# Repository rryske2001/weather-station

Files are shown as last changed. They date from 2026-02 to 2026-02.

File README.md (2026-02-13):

# 🌦️ Stacja Pogodowa ESP32 (Weather Station)








Projekt zaawansowanej, bezprzewodowej stacji pogodowej podzielonej na moduł bazowy (wyświetlacz) oraz zdalny węzeł czujnikowy. System monitoruje parametry środowiskowe w czasie rzeczywistym, prezentując dane na kolorowym wyświetlaczu TFT oraz rysując wykresy historyczne.

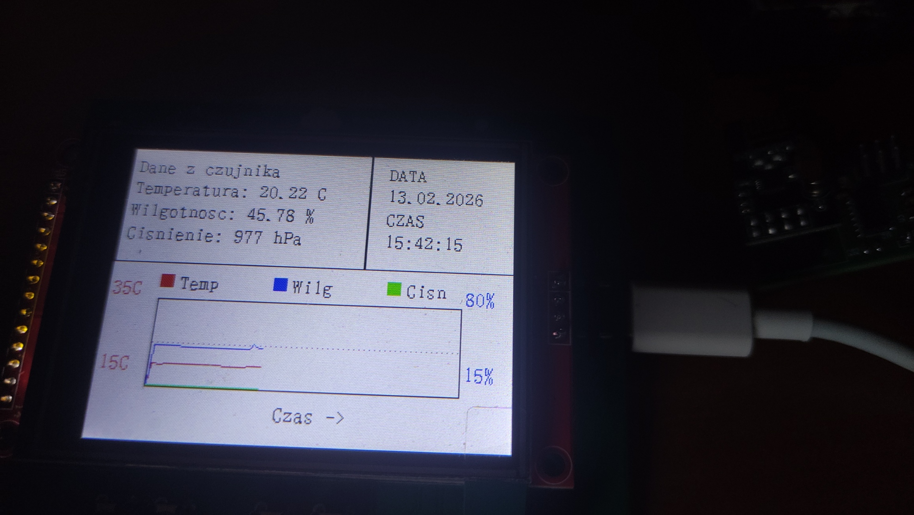
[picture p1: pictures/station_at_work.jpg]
Main Station

*Stacja w trakcie pracy - prezentacja aktualnych danych pomiarowych.*

## 🚀 Główne Funkcjonalności

* **Architektura Rozproszona:** Komunikacja bezprzewodowa między czujnikiem zewnętrznym a bazą przy użyciu modułów radiowych **NRF24L01** (2.4 GHz).
* **Interfejs Graficzny:** Wyświetlacz TFT LCD prezentujący:
    * Aktualną temperaturę, wilgotność i ciśnienie.
    * Wykresy historyczne (rysowanie linii w czasie rzeczywistym).
    * Aktualną datę i godzinę.
* **Synchronizacja Czasu:** Obsługa WiFi i protokołu NTP do automatycznego ustawiania zegara.
* **Sterowanie:** Fizyczne przyciski (SW1, SW2) do nawigacji między ekranami (dane liczbowe / wykresy).
* **Własne PCB:** Zaprojektowane od podstaw płytki drukowane dla obu modułów.

## 🛠️ Specyfikacja Sprzętowa (Hardware)

Projekt sprzętowy został wykonany w środowisku **KiCad**. Pliki produkcyjne znajdują się w katalogu `hardware`.

### 1. Moduł Wewnętrzny (Base Unit)
Centralna jednostka odbierająca dane i wyświetlająca wyniki.
* **MCU:** ESP32-WROOM-32E.
* **Komunikacja:** NRF24L01+ (Odbiornik) + WiFi.
* **Wyświetlacz:** TFT LCD (SPI).
* **Interfejs:** USB-C (zasilanie i programowanie przez układ CH340C).
* **PCB:** Dwuwarstwowa, elementy SMD i THT.

### 2. Moduł Zewnętrzny (Sensor Node)
Energooszczędny moduł pomiarowy.
* **MCU:** ATMEL AVR ATtiny 414.
* **Komunikacja:** NRF24L01+ (Nadajnik).
* **Czujniki:** Zintegrowany sensor środowiskowy (BME280).
* **PCB:** Kompaktowa płytka zoptymalizowana pod zasilanie bateryjne.

## 💻 Struktura Projektu (Software)

Kod źródłowy podzielony jest na dwa niezależne projekty w katalogu `software`:

```text
software/
├── external_module/        # Firmware nadajnika (zewnętrznego)
│   ├── src/                # Kod źródłowy C++
│   ├── platformio.ini      # Konfiguracja środowiska PlatformIO
│   └── ...
└── internal-module-podw/   # Firmware stacji bazowej (ESP32)
    ├── main/               # Główna logika aplikacji (ESP-IDF)
    ├── components/         # Sterowniki (LCD, NRF24, WiFi)
    ├── CMakeLists.txt      # Konfiguracja budowania ESP-IDF
    └── ...

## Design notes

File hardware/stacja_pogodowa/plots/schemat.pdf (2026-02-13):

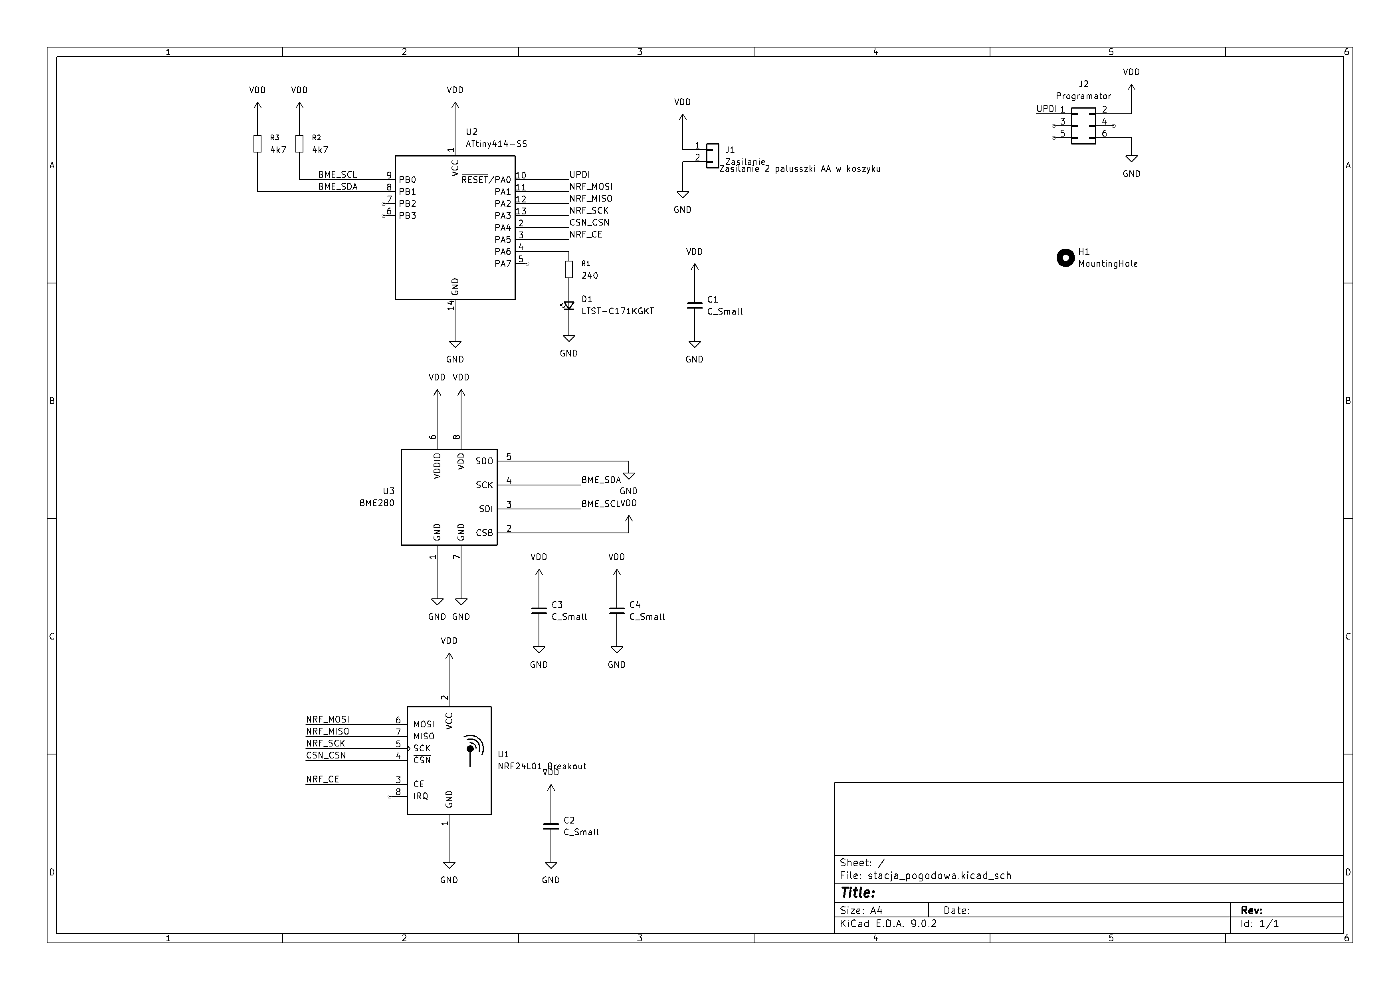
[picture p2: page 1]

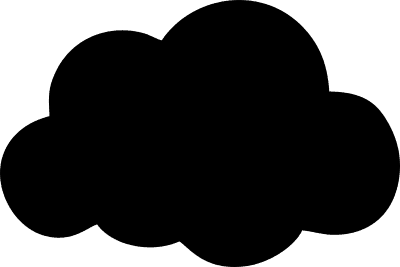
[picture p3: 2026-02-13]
hardware/stacja_pogody_moduł_wew/chmurka.png

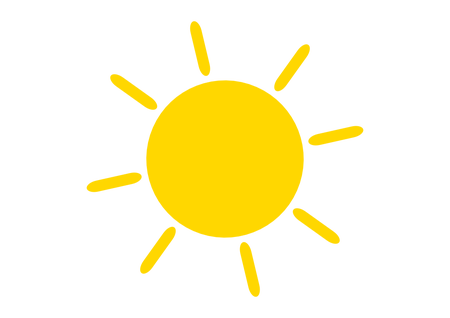
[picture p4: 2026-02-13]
hardware/stacja_pogody_moduł_wew/sloneczko.png

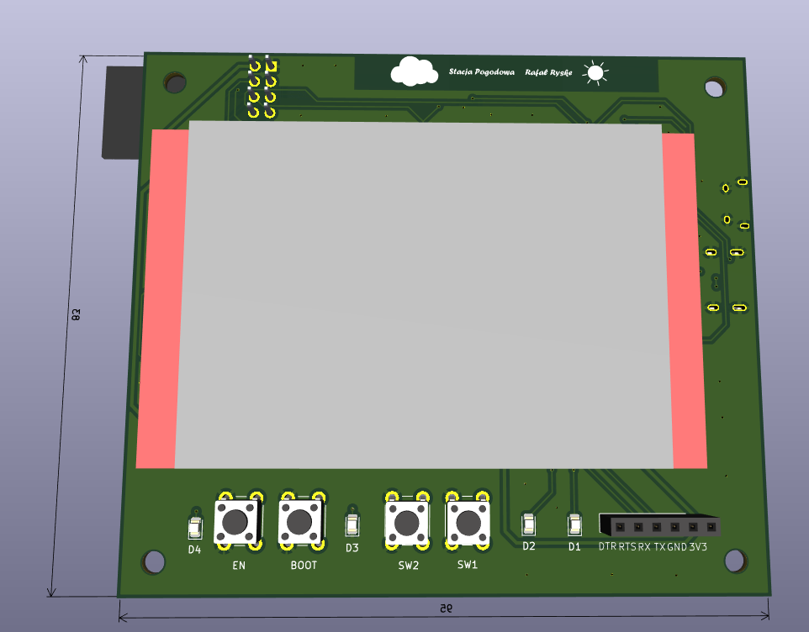
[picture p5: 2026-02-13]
pictures/top_pcb.png

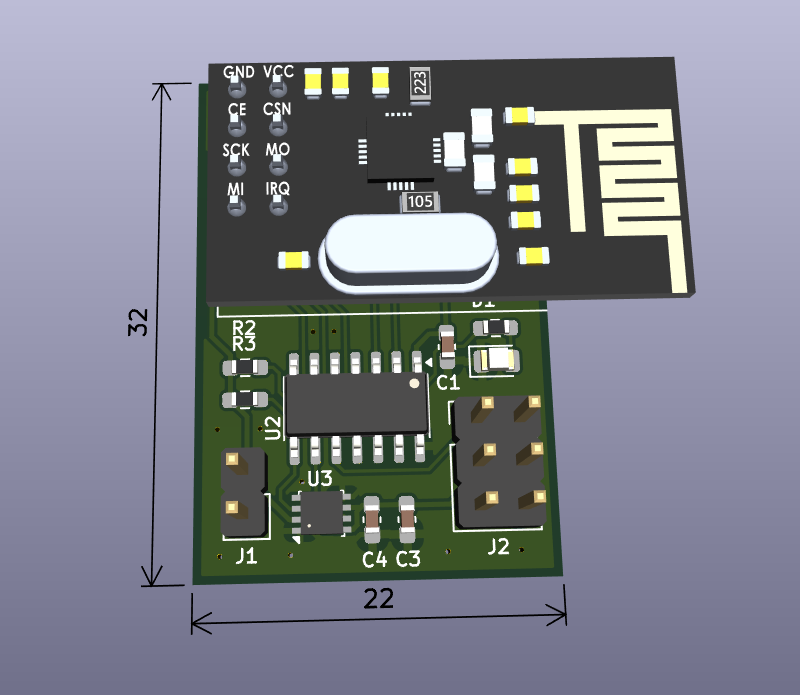
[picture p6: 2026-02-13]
pictures/top_pcb_external.png

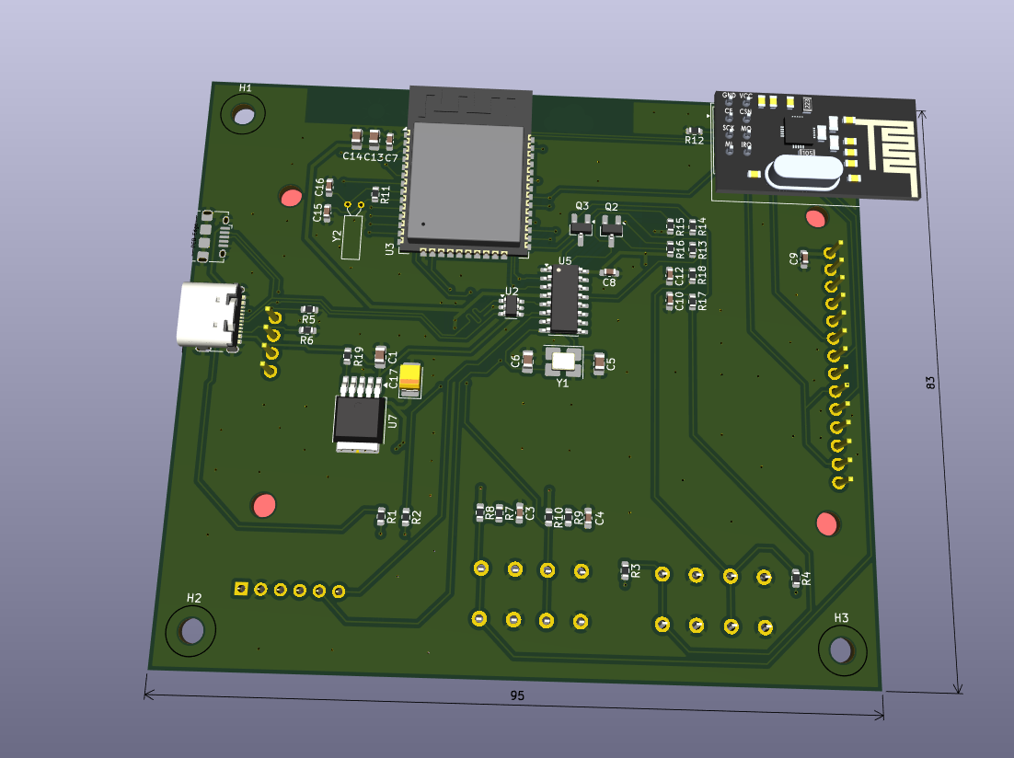
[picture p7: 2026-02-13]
pictures/bottom_pcb.png

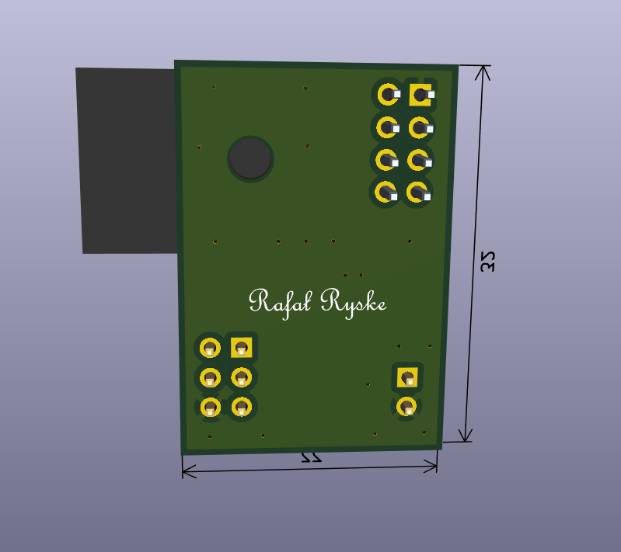
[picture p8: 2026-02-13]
pictures/bottom_pcb_external.png

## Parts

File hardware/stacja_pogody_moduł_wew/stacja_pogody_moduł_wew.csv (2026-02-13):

Reference | Qty | Value | DNP | Exclude from BOM | Exclude from Board | Footprint | Datasheet
C1,C4,C5,C6,C7,C9,C12,C13 | 8 | 100n |  |  |  | Capacitor_SMD:C_0603_1608Metric_Pad1.08x0.95mm_HandSolder | ~
C2,C3 | 2 | 10u |  |  |  | Capacitor_SMD:C_0805_2012Metric_Pad1.18x1.45mm_HandSolder | CS2012X5R106K160NRE
C10,C11 | 2 | 22p |  |  |  | Capacitor_SMD:C_0805_2012Metric_Pad1.18x1.45mm_HandSolder | ~
D1,D2,D3,D4 | 4 | LTST-C171KGKT |  |  |  | LED_SMD:LED_0805_2012Metric | ~
J1 | 1 | 10118194-0001LF |  |  |  | Connector_USB:USB_Micro-B_Amphenol_10118194-0001LF_Horizontal | ~
J2 | 1 | Conn_01x06 |  |  |  | Connector_PinSocket_2.54mm:PinSocket_1x06_P2.54mm_Vertical | ~
J3 | 1 | USB_C_Receptacle_USB2.0_16P |  |  |  |  | https://www.usb.org/sites/default/files/documents/usb_type-c.zip
Q1,Q2 | 2 | NPN |  |  |  | Package_TO_SOT_SMD:SOT-23_Handsoldering | https://ngspice.sourceforge.io/docs/ngspice-html-manual/manual.xhtml#cha_BJTs
R1,R2,R13,R14 | 4 | 240 |  |  |  | Resistor_SMD:R_0603_1608Metric | ~
R3,R4,R5,R6,R10,R12 | 6 | 1k |  |  |  | Resistor_SMD:R_0603_1608Metric | ~
R7,R8,R9,R11 | 4 | 10k |  |  |  | Resistor_SMD:R_0603_1608Metric | ~
SW1,SW2,SW3,SW5 | 4 | SW_MEC_5G |  |  |  | Button_Switch_THT:SW_PUSH_6mm_H4.3mm | http://www.apem.com/int/index.php?controller=attachment&id_attachment=488
U1 | 1 | NRF24L01_Breakout |  |  |  | RF_Module:nRF24L01_Breakout | http://www.nordicsemi.com/eng/content/download/2730/34105/file/nRF24L01_Product_Specification_v2_0.pdf
U2 | 1 | LCD |  |  |  | Wyswietlacz_LCD:LCD_2_8
U3 | 1 | LM1117RS-3.3V |  |  |  | Package_TO_SOT_SMD:TO-252-2 | http://www.ti.com/lit/ds/symlink/lm1117.pdf
U4 | 1 | ESP32-WROOM-32E-N4 |  |  |  | RF_Module:ESP32-WROOM-32E | https://www.espressif.com/sites/default/files/documentation/esp32-wroom-32e_esp32-wroom-32ue_datasheet_en.pdf
U5 | 1 | CH340G |  |  |  | Package_SO:SOIC-16_3.9x9.9mm_P1.27mm | http://www.datasheet5.com/pdf-local-2195953
Y2 | 1 | 3225-12M-SR |  |  |  | Crystal:Crystal_SMD_3225-4Pin_3.2x2.5mm_HandSoldering | ~

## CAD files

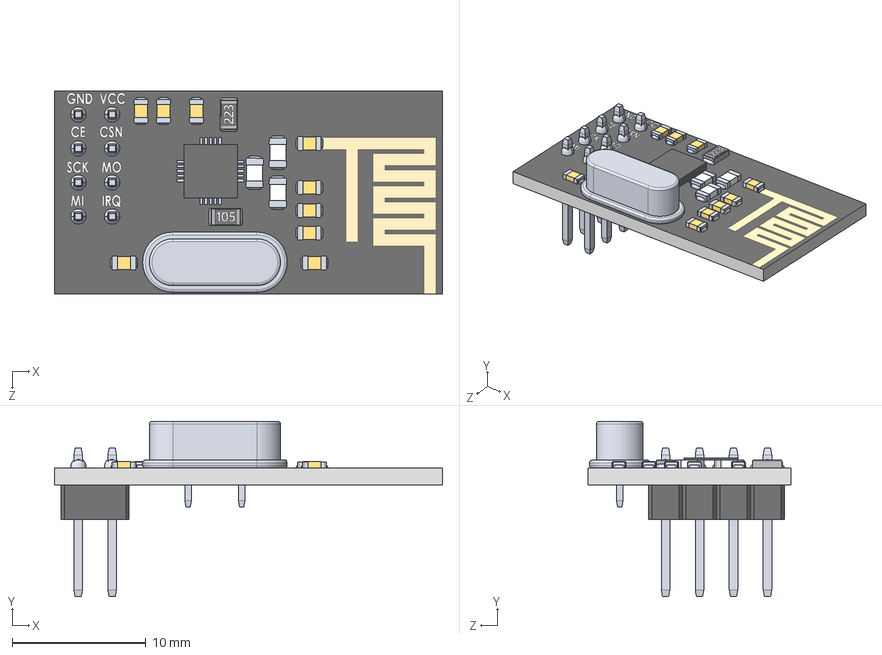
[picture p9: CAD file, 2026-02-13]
hardware/stacja_pogodowa/Wireless Radio Transmitter and Receiver nRF24L01.STEP
29.0 x 13.1 x 15.2 mm
nrfboard
CrystalOscillator
doubleMaleHeader x 4
solder x 8
1.7mmSmdCeramicCapacitor x 9
smdResistor223
smdResistor105
smdceramiccapacitorwhite x 3
4x4SMDchip

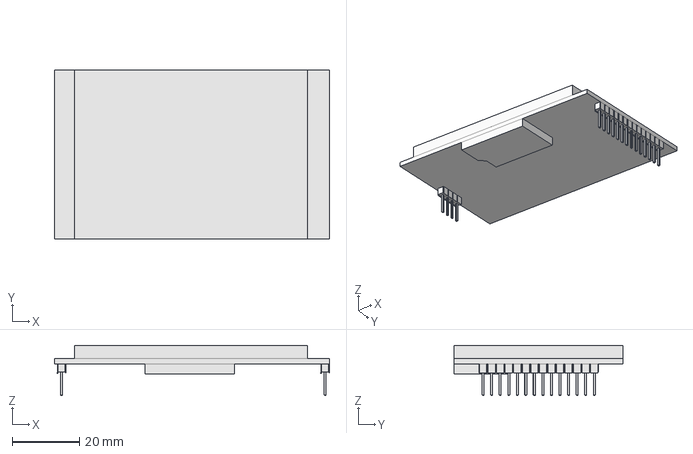
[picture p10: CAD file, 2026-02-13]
hardware/stacja_pogody_moduł_wew/lcd_fusion.FCStd
81.7 x 50.2 x 15.0 mm

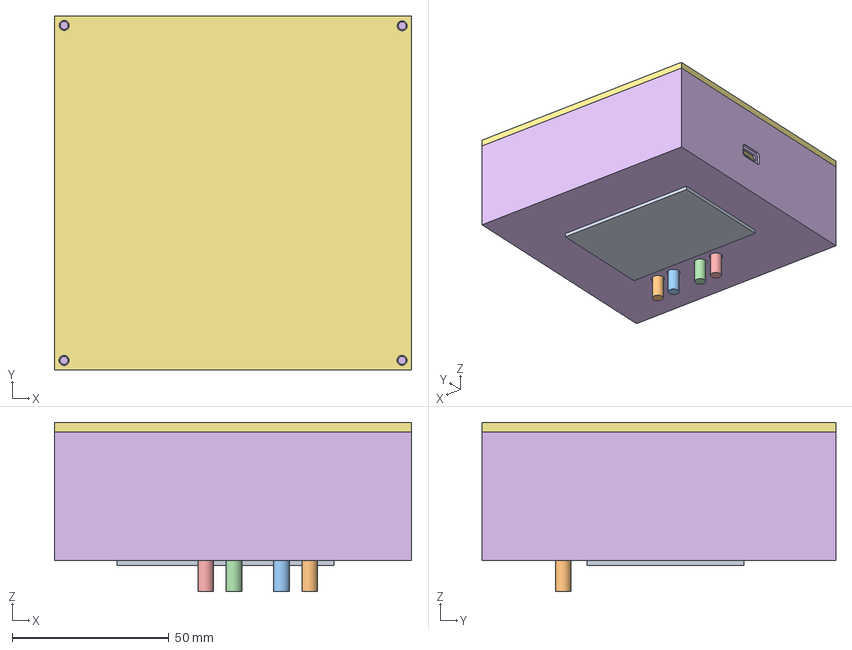
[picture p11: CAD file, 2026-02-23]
obudowa_modul_wew/zlozenie.FCStd
114.0 x 113.0 x 54.0 mm
stacja_pogody_moduł_wew1_001
nakladka_przycisk-nakladka1_001
nakladka_przycisk-nakladka1_002
nakladka_przycisk-nakladka1_003
nakladka_przycisk-nakladka1_004
obudowa_zewn-Zawartość1_001
obudowa_zewn-wieczko1_001

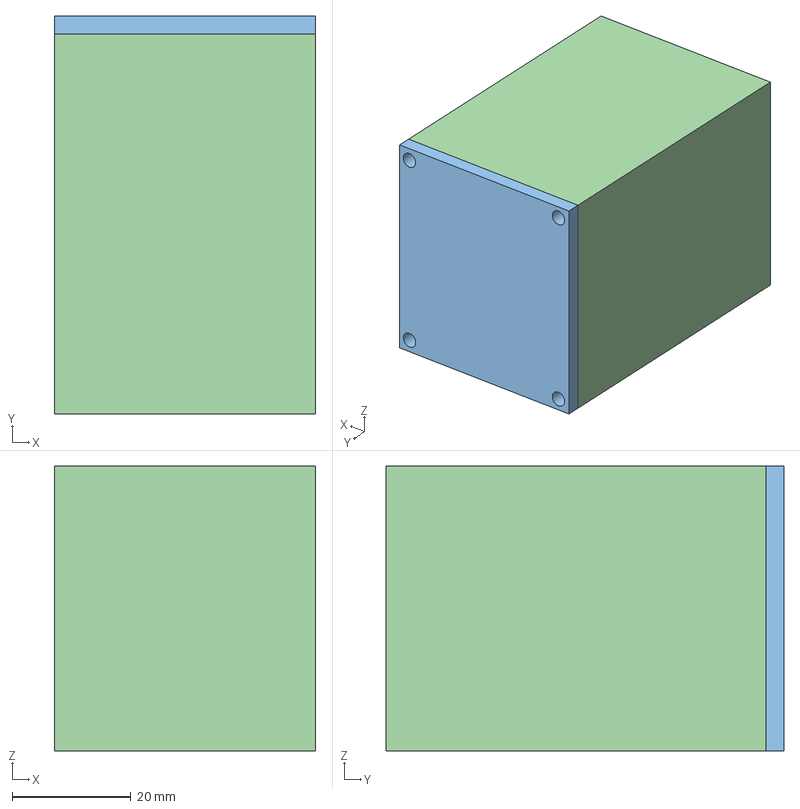
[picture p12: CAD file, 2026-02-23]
obudowa_modul_zewn_v2/obudowa_zewn.FCStd
44.0 x 67.0 x 48.0 mm
stacja_pogodowa
Zawartość
obudowa

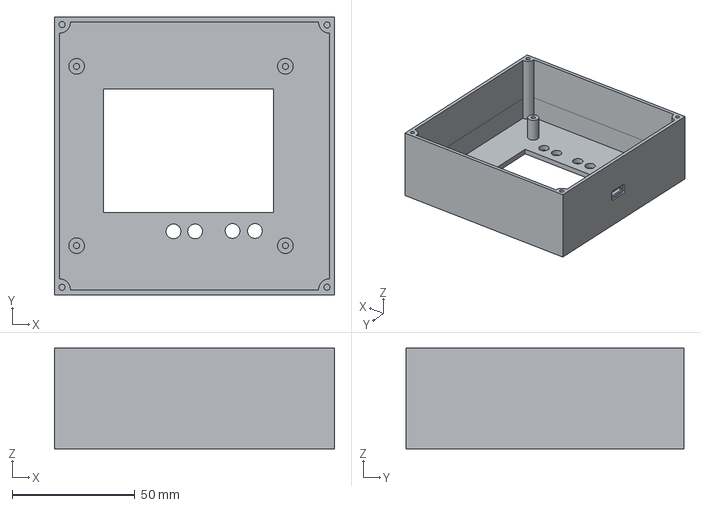
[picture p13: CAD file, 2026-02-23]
obudowa_modul_wew/obudowa_zewn-Zawartość.step
114.0 x 113.0 x 41.0 mm

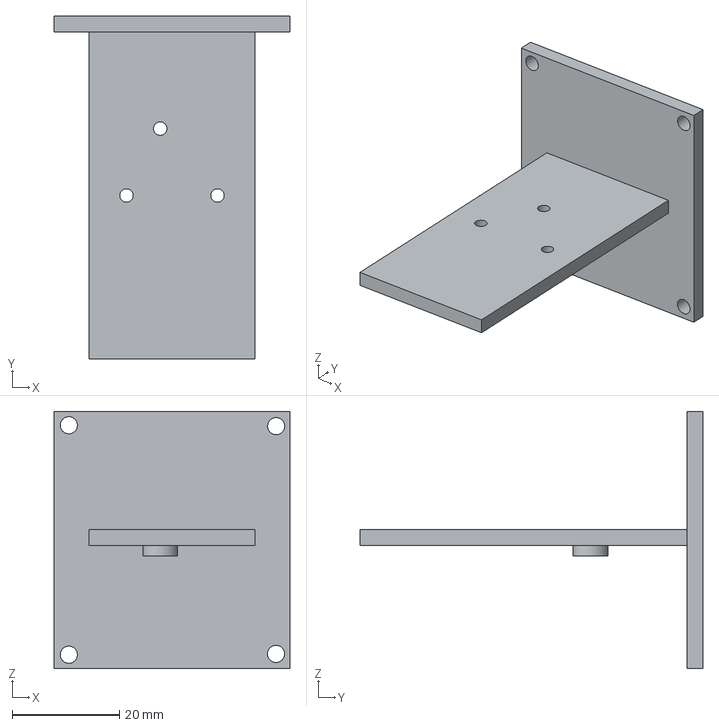
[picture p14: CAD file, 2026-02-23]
obudowa_modul_zewn_v2/obudowa_zewn-Zawartość.step
44.0 x 64.0 x 48.0 mm

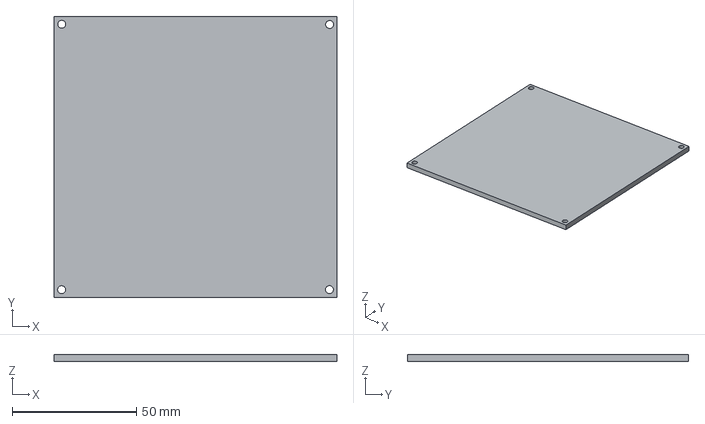
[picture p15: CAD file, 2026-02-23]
obudowa_modul_wew/obudowa_zewn-wieczko.step
114.0 x 113.0 x 3.00 mm

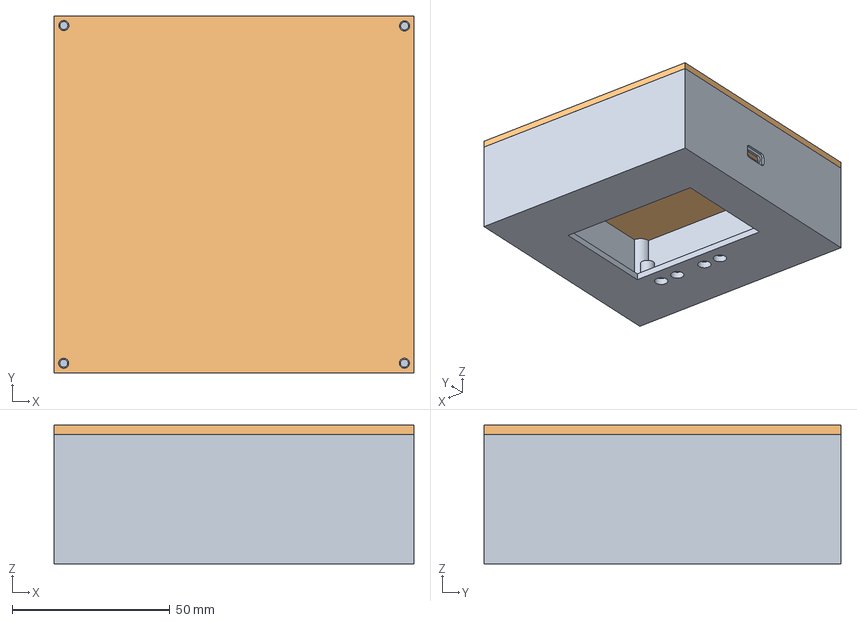
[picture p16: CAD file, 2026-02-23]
obudowa_modul_wew/obudowa_zewn.FCStd
114.0 x 113.0 x 44.0 mm
Zawartość
wieczko

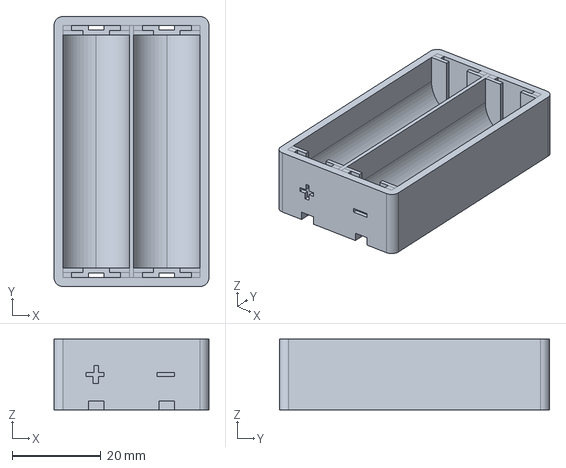
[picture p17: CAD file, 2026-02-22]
obudowa_modul_zewn_v2/2AA_CAD.fcstd
35.0 x 61.0 x 16.0 mm

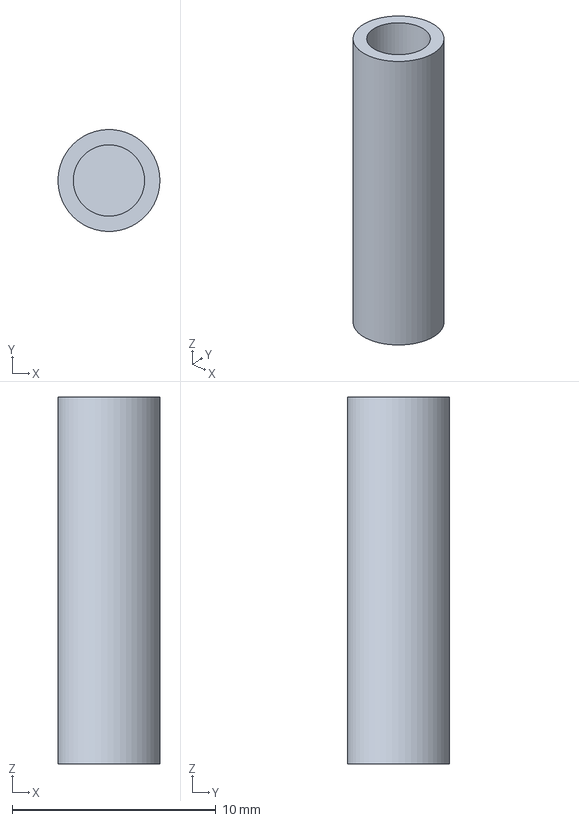
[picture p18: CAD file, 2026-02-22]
obudowa_modul_wew/nakladka_przycisk.FCStd
5.00 x 5.00 x 18.0 mm

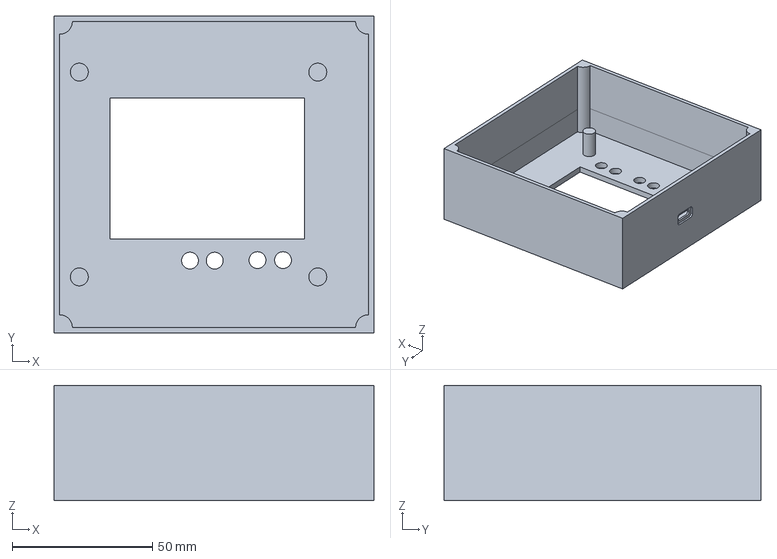
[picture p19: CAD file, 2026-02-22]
obudowa_modul_wew/obudowa_zewn — kopia.FCStd
114.0 x 113.0 x 41.0 mm

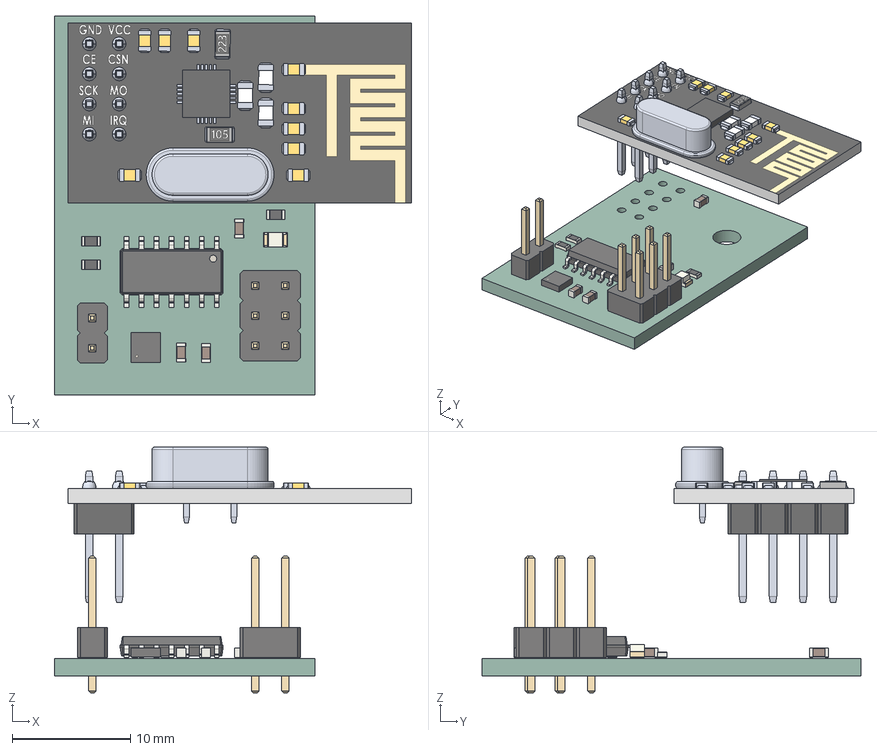
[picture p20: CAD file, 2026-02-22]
obudowa_modul_zewn_v2/stacja_pogodowa.step
30.2 x 32.0 x 20.8 mm
PinHeader_1x02_P2.54mm_Vertical
LED_0805_2012Metric
R_0603_1608Metric x 3
nrfboard
CrystalOscillator
doubleMaleHeader x 4
solder x 8
1.7mmSmdCeramicCapacitor x 9
smdResistor223
smdResistor105
smdceramiccapacitorwhite x 3
4x4SMDchip
Bosch_LGA-8_2.5x2.5mm_P0.65mm_ClockwisePinNumbering
PinHeader_2x03_P2.54mm_Vertical
C_0603_1608Metric x 4
SOIC-14_3.9x8.7mm_P1.27mm
stacja_pogodowa_PCB

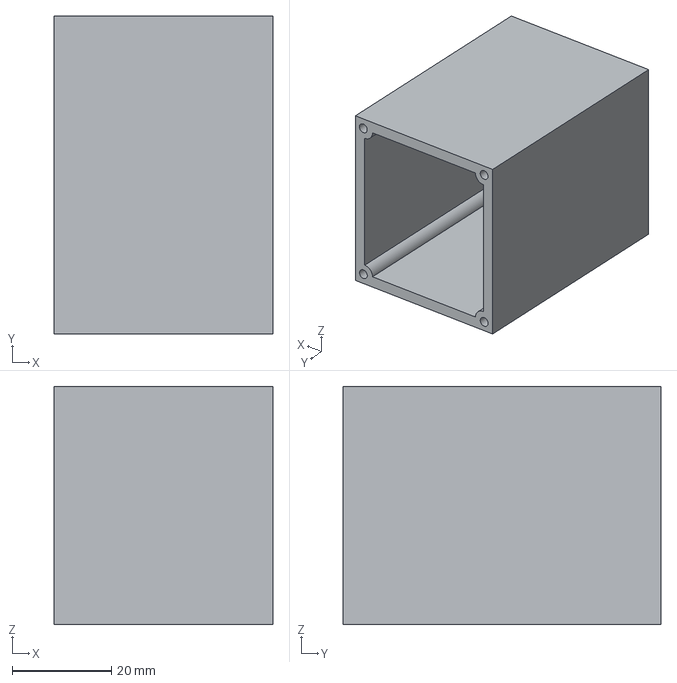
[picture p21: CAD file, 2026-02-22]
obudowa_modul_zewn_v2/obudowa_zewn-obudowa.step
44.0 x 64.0 x 48.0 mm

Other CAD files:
hardware/stacja_pogody_moduł_wew/lcd_019.step
obudowa_modul_zewn_v2/zlozenie.FCStd
obudowa_modul_zewn_v2/obudowa_zewn — kopia.FCStd
obudowa_modul_wew/nakladka_przycisk-nakladka.step
obudowa_modul_zewn/2AA.stl
obudowa_modul_zewn/2AA_CAD.fcstd
obudowa_modul_zewn/obudowa2-cialo.step
obudowa_modul_zewn/obudowa2-wieczko.step
obudowa_modul_zewn/obudowa2.FCStd
obudowa_modul_zewn/zlozenie.FCStd
obudowa_modul_zewn_v2/2AA_CAD-Body.step

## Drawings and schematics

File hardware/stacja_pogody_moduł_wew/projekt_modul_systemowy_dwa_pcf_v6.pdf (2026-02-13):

105 | 36
INT A1 4.7k | R³

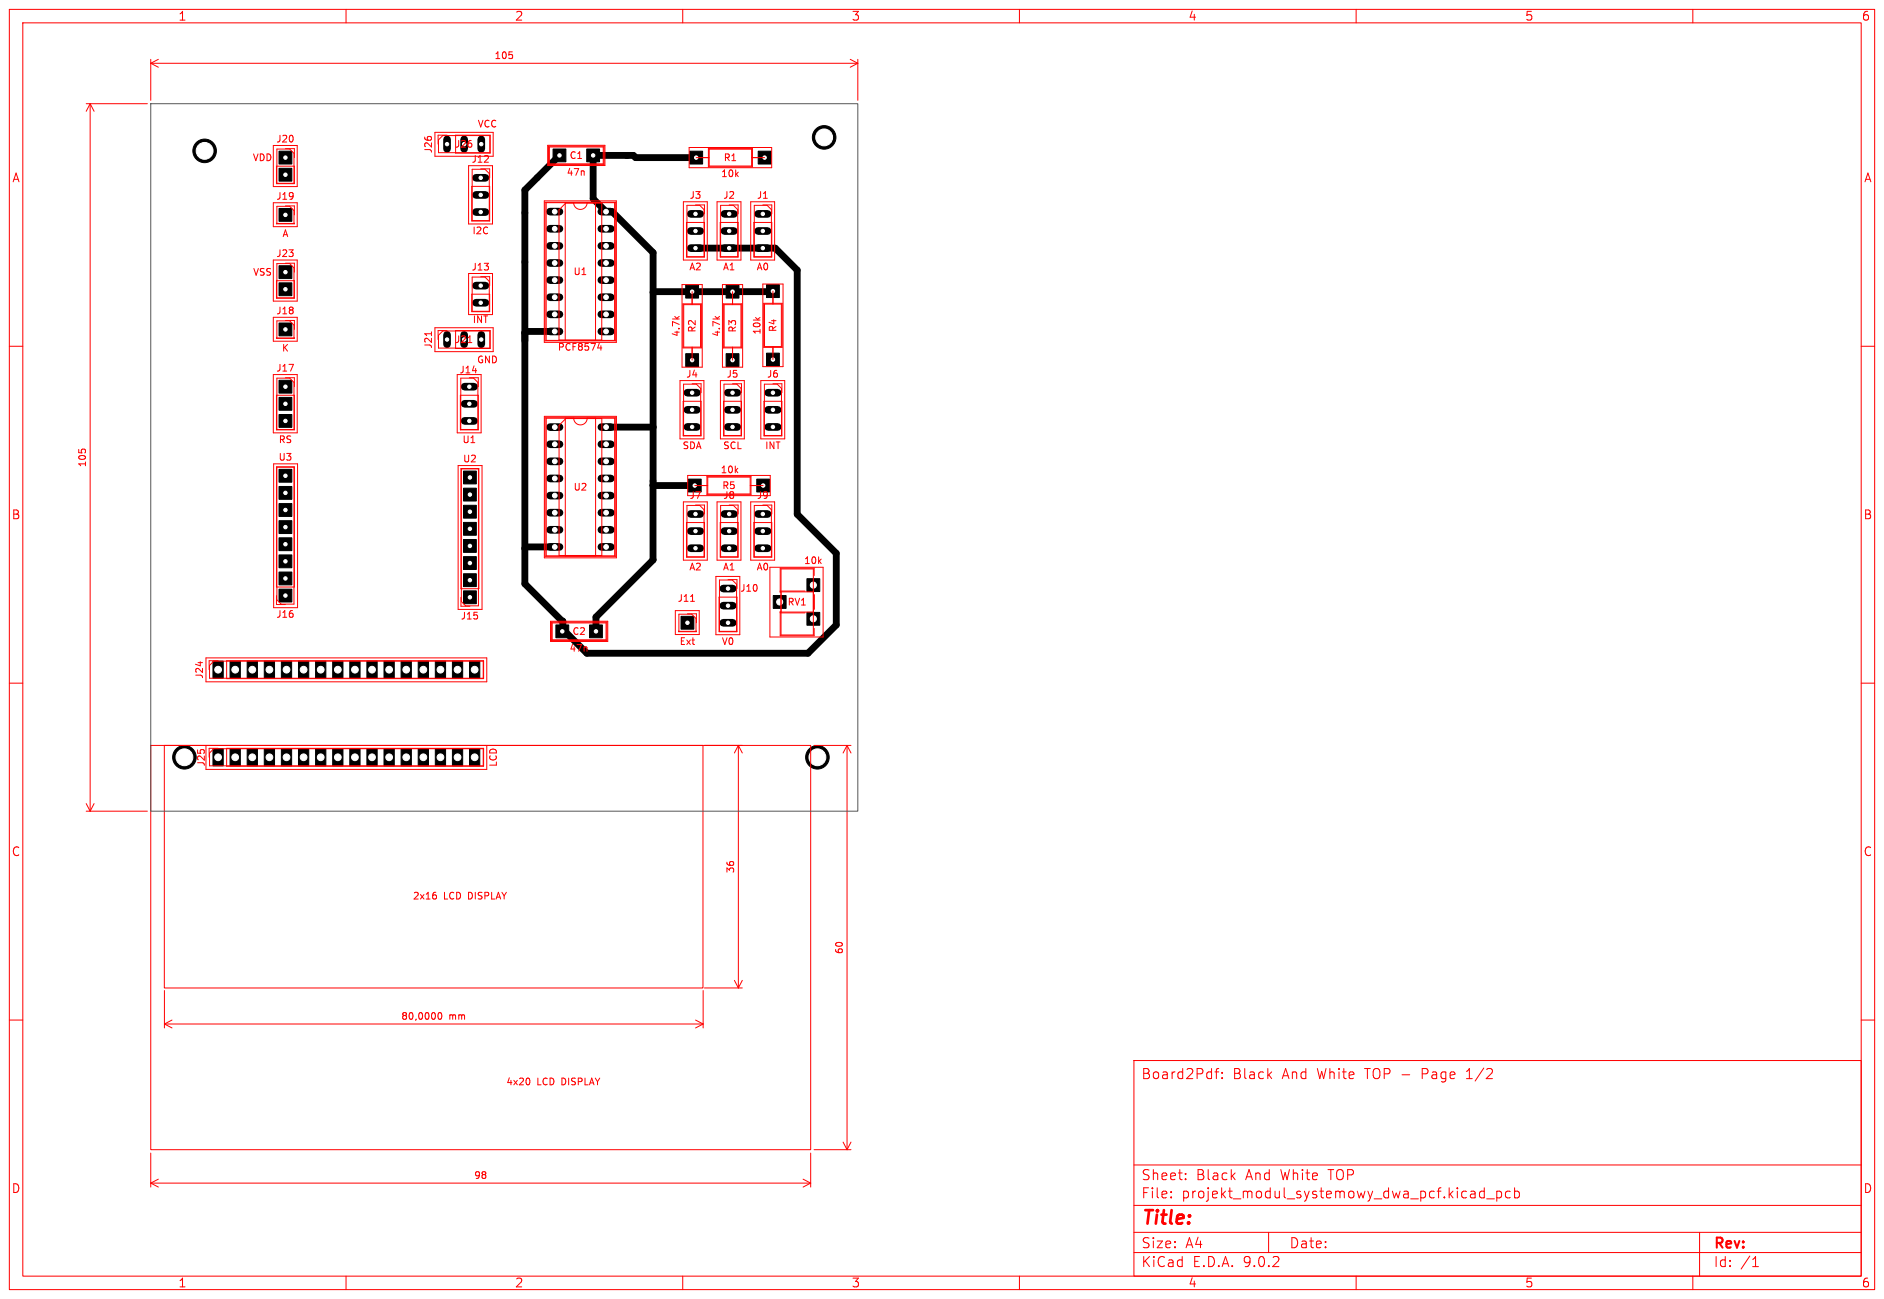
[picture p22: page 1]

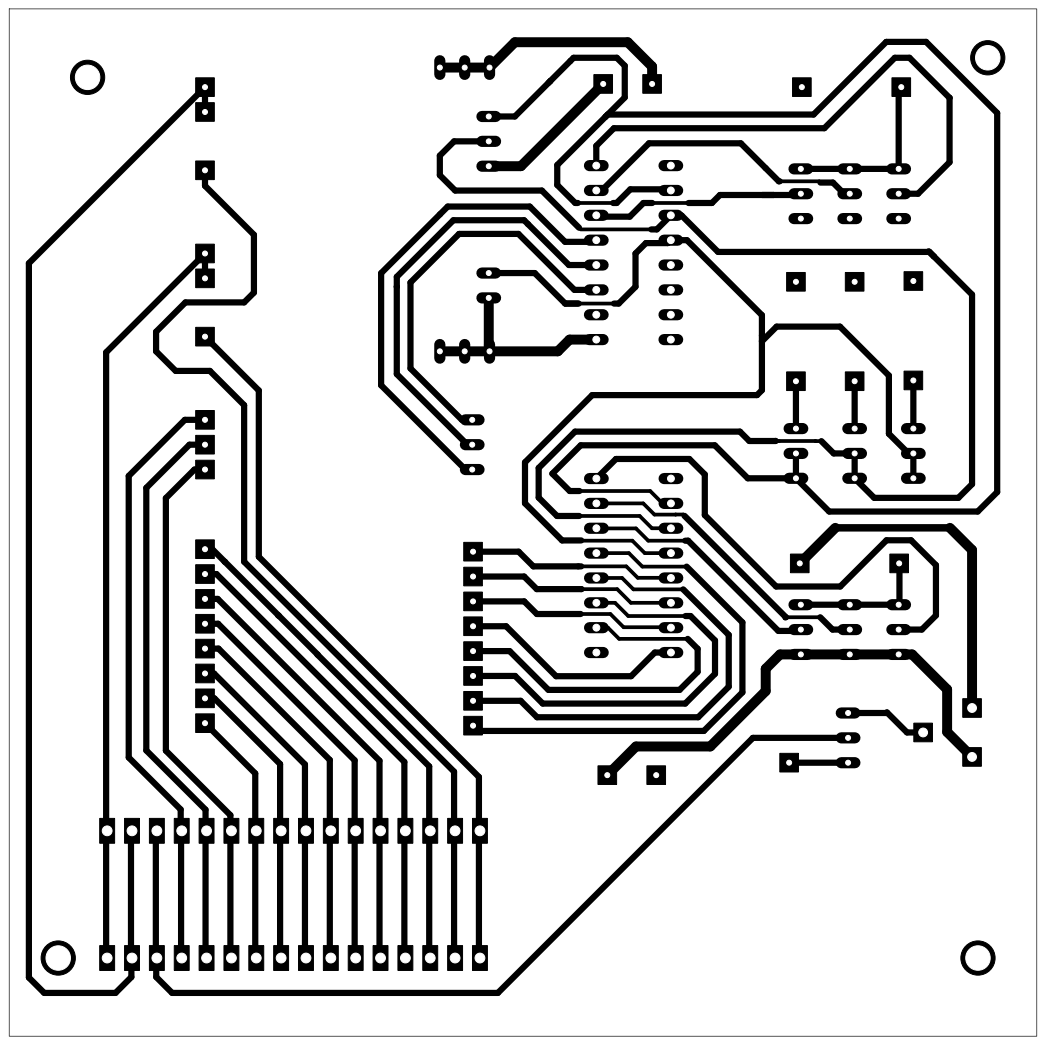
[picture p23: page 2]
D Date: KiCad; E.D.A. 9.0.2 Size: A4; Rev:; Id: /1 Title: File: projekt_modul_systemowy_dwa_pcf.kicad_pcb Sheet: Black; And; White; BOT Board2Pdf:; Black; BOT -; Page 2/2

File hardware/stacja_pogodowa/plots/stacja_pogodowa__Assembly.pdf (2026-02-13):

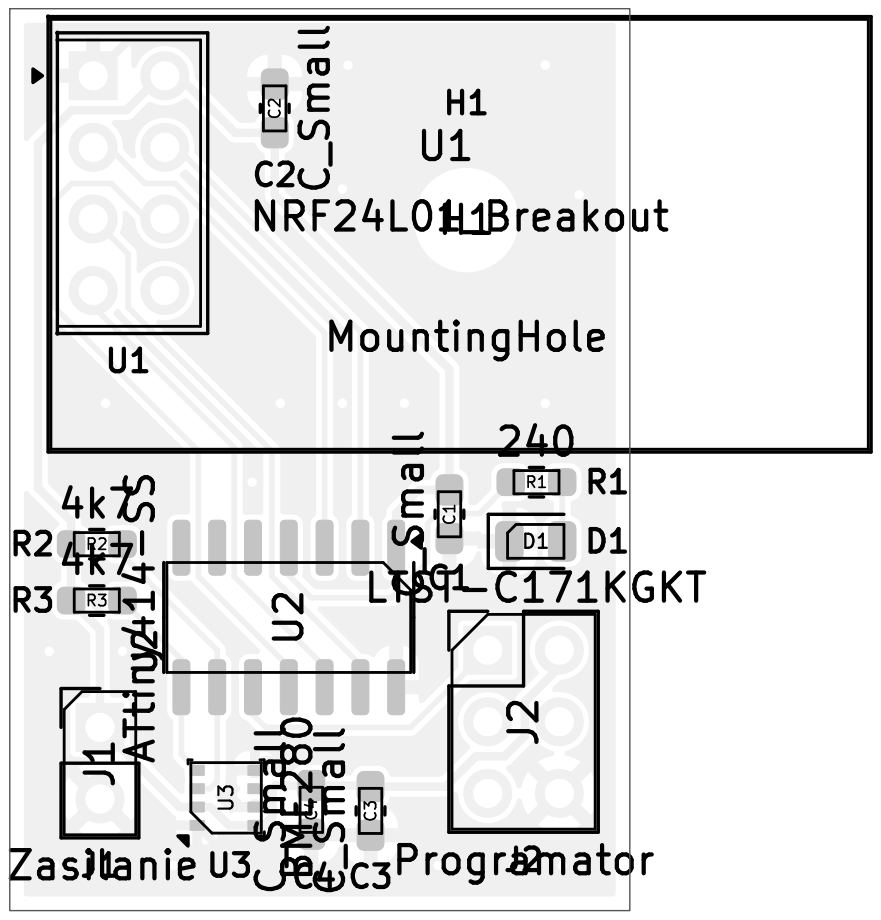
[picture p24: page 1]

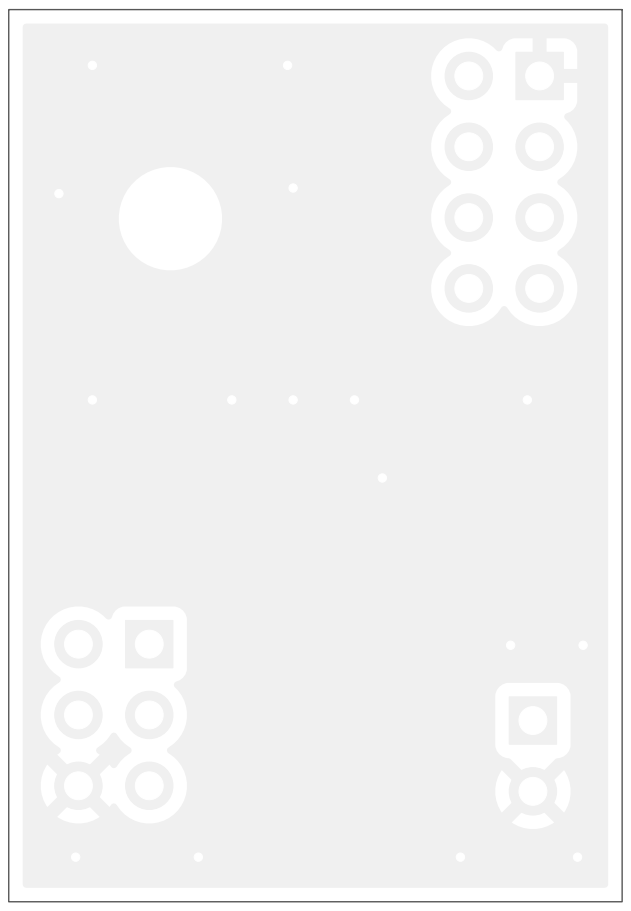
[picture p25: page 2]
D Date: KiCad; E.D.A. 9.0.2 Size: A4; Rev:; Id: /1 Title: File: stacja_pogodowa.kicad_pcb Sheet: Black; And; White; BOT Board2Pdf:; Black; BOT -; Page 2/2

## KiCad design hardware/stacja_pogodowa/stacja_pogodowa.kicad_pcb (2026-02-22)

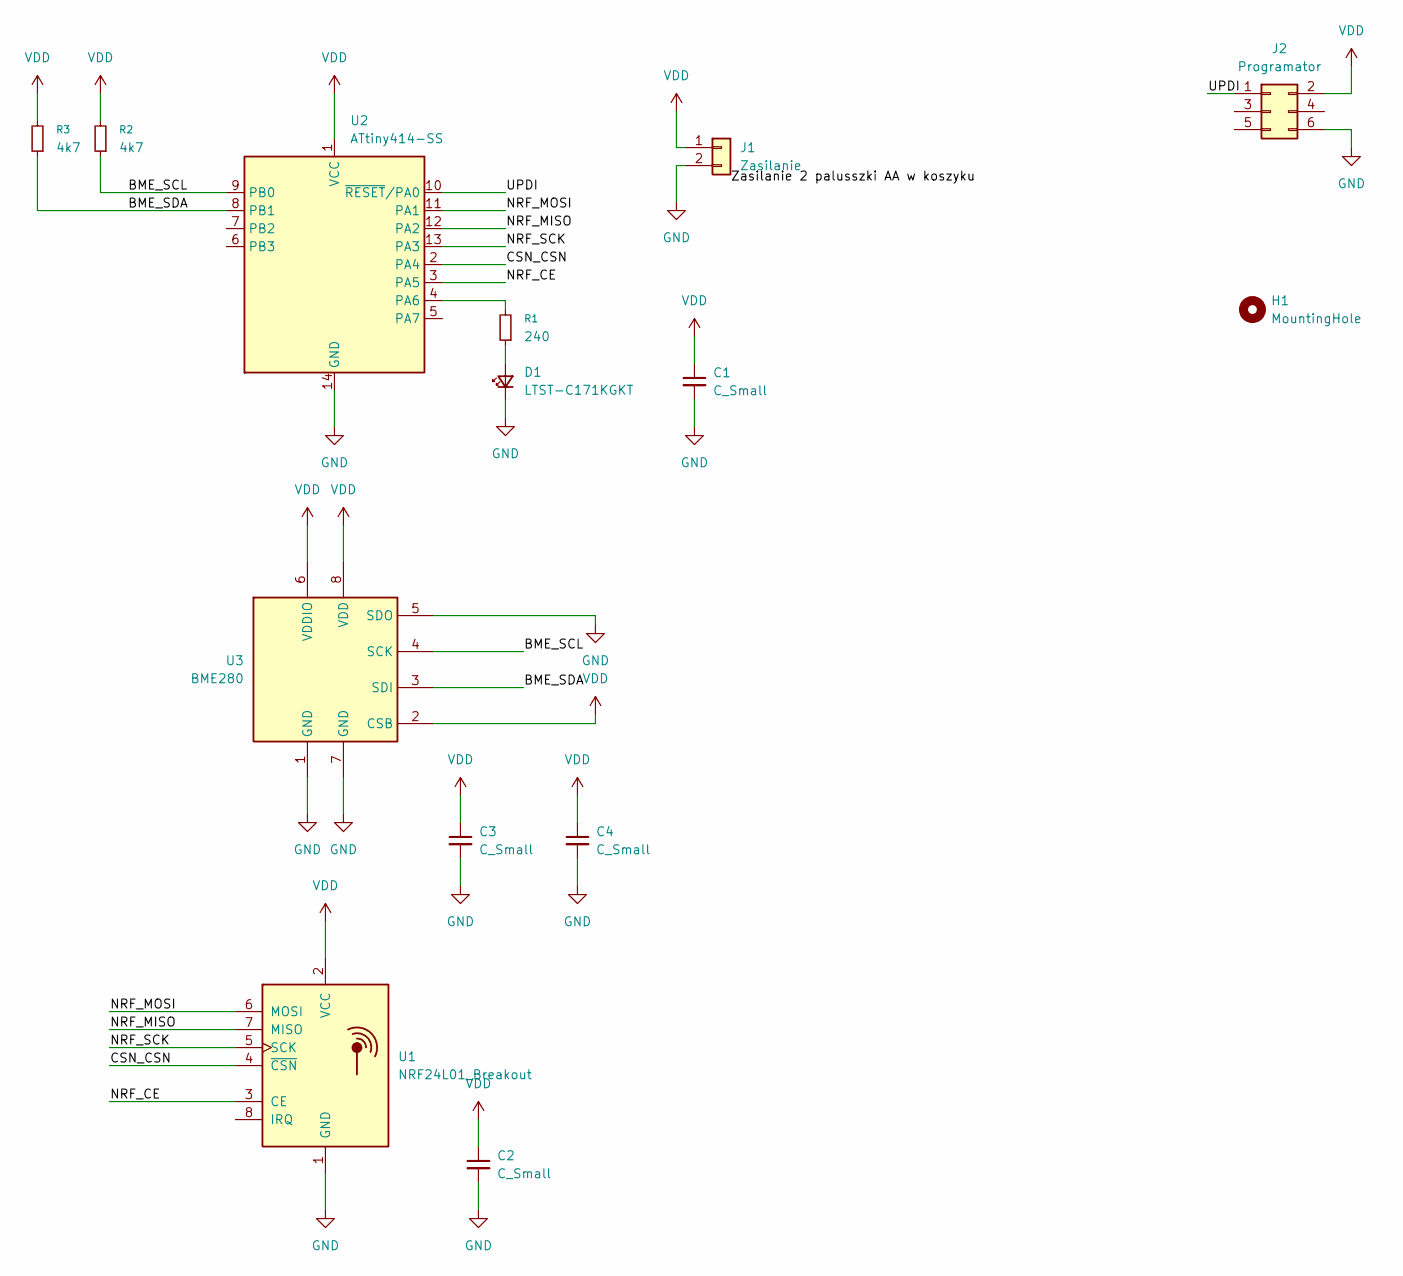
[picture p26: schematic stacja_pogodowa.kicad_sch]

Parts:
C1, C2, C3, C4: C_Small; C_0603_1608Metric_Pad1.08x0.95mm_HandSolder
D1: LTST-C171KGKT; LED_0805_2012Metric
H1: MountingHole; MountingHole_3.2mm_M3
J1: Zasilanie; PinHeader_1x02_P2.54mm_Vertical
J2: Programator; PinHeader_2x03_P2.54mm_Vertical
R1: 240; R_0603_1608Metric_Pad0.98x0.95mm_HandSolder
R2, R3: 4k7; R_0603_1608Metric_Pad0.98x0.95mm_HandSolder
U1: NRF24L01_Breakout; nRF24L01_Breakout
U2: ATtiny414-SS; SOIC-14_3.9x8.7mm_P1.27mm
U3: BME280; Bosch_LGA-8_2.5x2.5mm_P0.65mm_ClockwisePinNumbering

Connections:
/BME_SCL: R2.1, U2.9 (PB0), U3.4 (SCK)
/BME_SDA: R3.1, U2.8 (PB1), U3.3 (SDI)
/CSN_CSN: U1.4 (~CSN), U2.2 (PA4)
/NRF_CE: U1.3 (CE), U2.3 (PA5)
/NRF_MISO: U1.7 (MISO), U2.12 (PA2)
/NRF_MOSI: U1.6 (MOSI), U2.11 (PA1)
/NRF_SCK: U1.5 (SCK), U2.13 (PA3)
/UPDI: J2.1, U2.10 (~RESET/PA0)
GND: C1.2, C2.2, C3.2, C4.2, D1.1 (K), J1.2, J2.6, U1.1 (GND), U2.14 (GND), U3.1 (GND), U3.5 (SDO), U3.7 (GND)
unnamed: D1.2 (A), R1.1
unnamed: R1.2, U2.4 (PA6)
VDD: C1.1, C2.1, C3.1, C4.1, J1.1, J2.2, R2.2, R3.2, U1.2 (VCC), U2.1 (VCC), U3.2 (CSB), U3.6 (VDDIO), U3.8 (VDD)

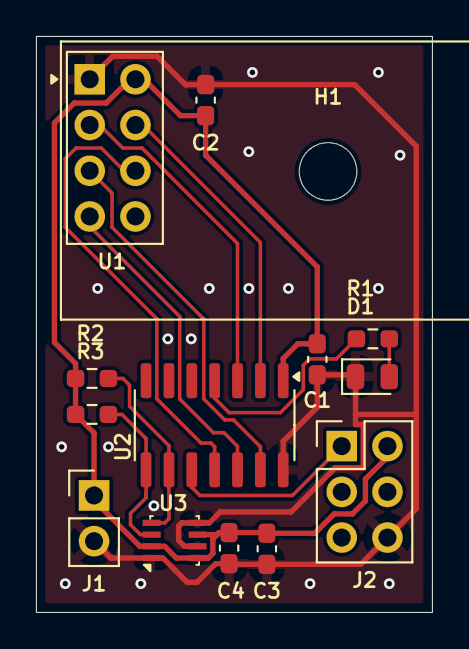
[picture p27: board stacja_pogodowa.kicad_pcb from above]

Board: 2 copper layers, 22.0 x 32.0 mm, 14 parts (0 on the bottom side), 12 nets.

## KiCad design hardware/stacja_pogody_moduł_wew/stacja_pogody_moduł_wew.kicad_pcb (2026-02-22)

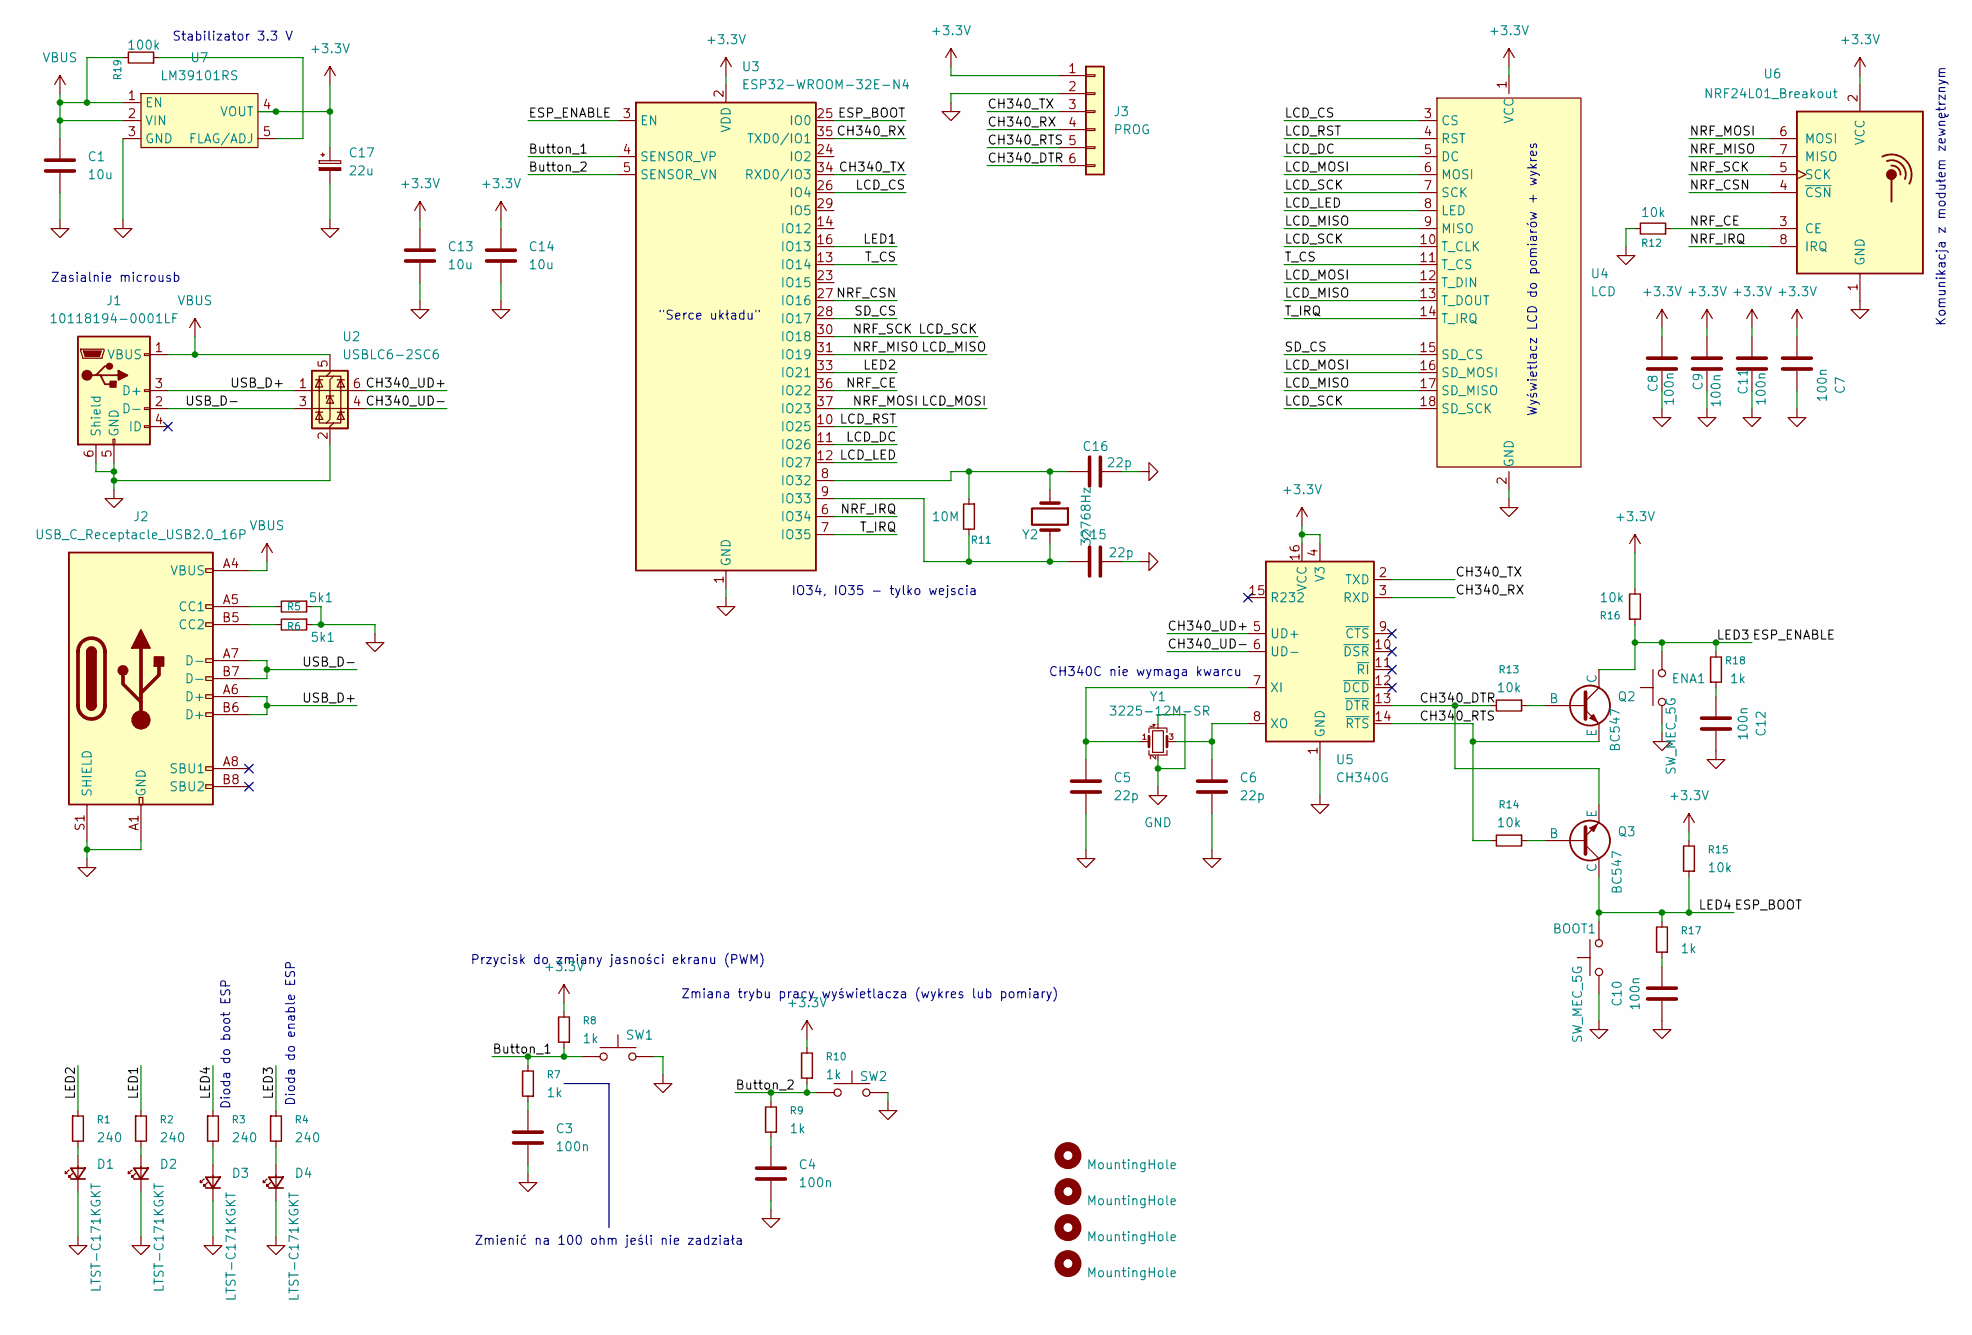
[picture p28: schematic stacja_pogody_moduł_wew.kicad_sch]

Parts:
BOOT1: SW_MEC_5G; SW_PUSH_6mm_H4.3mm
C1, C13, C14: 10u; C_0805_2012Metric_Pad1.18x1.45mm_HandSolder
C3, C4, C7, C8, C9, C10, C11, C12: 100n; C_0603_1608Metric_Pad1.08x0.95mm_HandSolder
C5, C6: 22p; C_0805_2012Metric_Pad1.18x1.45mm_HandSolder
C15, C16: 22p; C_0603_1608Metric_Pad1.08x0.95mm_HandSolder
C17: 22u; CP_EIA-3528-21_Kemet-B_HandSolder
D1, D2, D3, D4: LTST-C171KGKT; LED_0805_2012Metric
ENA1: SW_MEC_5G; SW_PUSH_6mm_H4.3mm
H1, H2, H3, H4: MountingHole; MountingHole_3.2mm_M3
J1: 10118194-0001LF; USB_Micro-B_Amphenol_10118194-0001LF_Horizontal
J2: USB_C_Receptacle_USB2.0_16P; USB_C_Receptacle_TME
J3: PROG; PinSocket_1x06_P2.54mm_Vertical
Q2, Q3: BC547; SOT-23_Handsoldering
R1, R2, R3, R4: 240; R_0603_1608Metric
R5, R6: 5k1; R_0603_1608Metric
R7, R8, R9, R10, R17, R18: 1k; R_0603_1608Metric
R11: 10M; R_0603_1608Metric
R12, R13, R14, R15, R16: 10k; R_0603_1608Metric
R19: 100k; R_0603_1608Metric
SW1, SW2: SW_MEC_5G; SW_PUSH_6mm_H4.3mm
U2: USBLC6-2SC6; SOT-23-6
U3: ESP32-WROOM-32E-N4; ESP32-WROOM-32E
U4: LCD; LCD_2_8
U5: CH340G; SOIC-16_3.9x9.9mm_P1.27mm
U6: NRF24L01_Breakout; nRF24L01_Breakout
U7: LM39101RS; TO-252-5_TabPin3
Y1: 3225-12M-SR; Crystal_SMD_3225-4Pin_3.2x2.5mm_HandSoldering
Y2: 32768Hz; Crystal_DS26_D2.0mm_L6.0mm_Horizontal

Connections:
+3.3V: C7.2, C8.2, C9.2, C11.2, C13.2, C14.2, C17.1, J3.1, R8.2, R10.2, R15.2, R16.2, U3.2 (VDD), U4.1 (VCC), U5.4 (V3), U5.16 (VCC), U6.2 (VCC), U7.4 (VOUT)
/Button_1: R7.2, R8.1, SW1.2 (A), U3.4 (SENSOR_VP)
/Button_2: R9.2, R10.1, SW2.2 (A), U3.5 (SENSOR_VN)
/CH340_DTR: J3.6, Q3.3 (E), R13.2, U5.13 (~DTR)
/CH340_RTS: J3.5, Q2.3 (E), R14.2, U5.14 (~RTS)
/CH340_RX: J3.4, U3.35 (TXD0/IO1), U5.3 (RXD)
/CH340_TX: J3.3, U3.34 (RXD0/IO3), U5.2 (TXD)
/CH340_UD+: U2.6 (I/O1), U5.5 (UD+)
/CH340_UD-: U2.4 (I/O2), U5.6 (UD-)
/ESP_BOOT: BOOT1.1, Q3.1 (C), R3.1, R15.1, R17.2, U3.25 (IO0); also elsewhere on the board
/ESP_ENABLE: ENA1.1, Q2.1 (C), R4.1, R16.1, R18.2, U3.3 (EN); also elsewhere on the board
/LCD_CS: U3.26 (IO4), U4.3 (CS)
/LCD_DC: U3.11 (IO26), U4.5 (DC)
/LCD_LED: U3.12 (IO27), U4.8 (LED)
/LCD_MISO: U3.31 (IO19), U4.9 (MISO), U4.13 (T_DOUT), U4.17 (SD_MISO), U6.7 (MISO)
/LCD_MOSI: U3.37 (IO23), U4.6 (MOSI), U4.12 (T_DIN), U4.16 (SD_MOSI), U6.6 (MOSI)
/LCD_RST: U3.10 (IO25), U4.4 (RST)
/LCD_SCK: U3.30 (IO18), U4.7 (SCK), U4.10 (T_CLK), U4.18 (SD_SCK), U6.5 (SCK)
/LED1: R2.1, U3.16 (IO13)
/LED2: R1.1, U3.33 (IO21)
/NRF_CE: R12.1, U3.36 (IO22), U6.3 (CE)
/NRF_CSN: U3.27 (IO16), U6.4 (~CSN)
/NRF_IRQ: U3.6 (IO34), U6.8 (IRQ)
/SD_CS: U3.28 (IO17), U4.15 (SD_CS)
/T_CS: U3.13 (IO14), U4.11 (T_CS)
/T_IRQ: U3.7 (IO35), U4.14 (T_IRQ)
/USB_D+: J1.3 (D+), J2.A6 (D+), J2.B6 (D+), U2.1 (I/O1)
/USB_D-: J1.2 (D-), J2.A7 (D-), J2.B7 (D-), U2.3 (I/O2)
GND: BOOT1.2, C1.1, C3.1, C4.1, C5.2, C6.2, C7.1, C8.1, C9.1, C10.2, C11.1, C12.2, C13.1, C14.1, C15.2, C16.2, C17.2, D1.1 (K), D2.1 (K), D3.1 (K), D4.1 (K), ENA1.2, J1.5 (GND), J1.6 (Shield), J2.A1 (GND), J2.A12 (GND), J2.B1 (GND), J2.B12 (GND), J2.S1 (SHIELD), J3.2, R5.1, R6.1, R12.2, SW1.1 (A), SW2.1 (A), U2.2 (GND), U3.1 (GND), U3.15 (GND), U3.38 (GND), U3.39 (GND), U4.2 (GND), U5.1 (GND), U6.1 (GND), U7.3 (GND), Y1.2, Y1.4; also elsewhere on the board
unnamed: C3.2, R7.1
unnamed: C4.2, R9.1
unnamed: C10.1, R17.1
unnamed: C12.1, R18.1
unnamed: D1.2 (A), R1.2
unnamed: D2.2 (A), R2.2
unnamed: D3.2 (A), R3.2
unnamed: D4.2 (A), R4.2
unnamed: J2.A5 (CC1), R5.2
unnamed: J2.B5 (CC2), R6.2
unnamed: Q2.2 (B), R13.1
unnamed: Q3.2 (B), R14.1
unnamed: C16.1, R11.1, U3.8 (IO32), Y2.1
unnamed: C15.1, R11.2, U3.9 (IO33), Y2.2
unnamed: C5.1, U5.7 (XI), Y1.1
unnamed: C6.1, U5.8 (XO), Y1.3
unnamed: R19.1, U7.5 (FLAG/ADJ)
VBUS: C1.2, J1.1 (VBUS), J2.A4 (VBUS), J2.A9 (VBUS), J2.B4 (VBUS), J2.B9 (VBUS), R19.2, U2.5 (VBUS), U7.1 (EN), U7.2 (VIN)

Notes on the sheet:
Wyświetlacz LCD do pomiarów + wykres
Komunikacja z modułem zewnętrznym
CH340C nie wymaga kwarcu
Zasialnie microusb
IO34, IO35 - tylko wejscia
Dioda do enable ESP
Dioda do boot ESP
Zmiana trybu pracy wyświetlacza (wykres lub pomiary)
Przycisk do zmiany jasności ekranu (PWM)
"Serce układu"
Stabilizator 3.3 V
Zmienić na 100 ohm jeśli nie zadziała

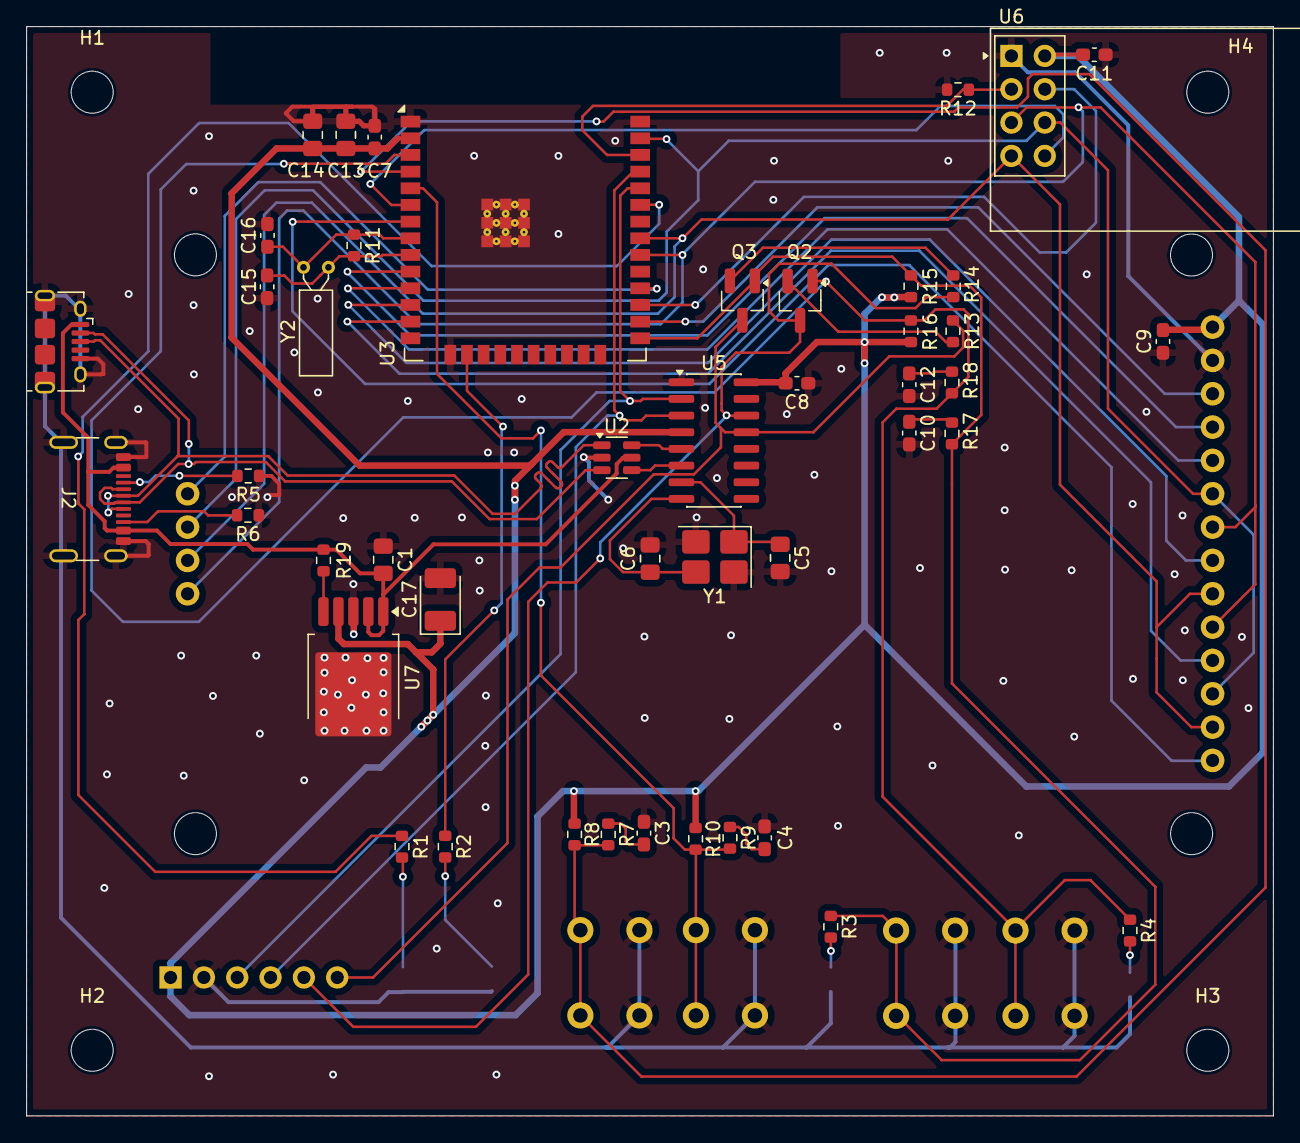
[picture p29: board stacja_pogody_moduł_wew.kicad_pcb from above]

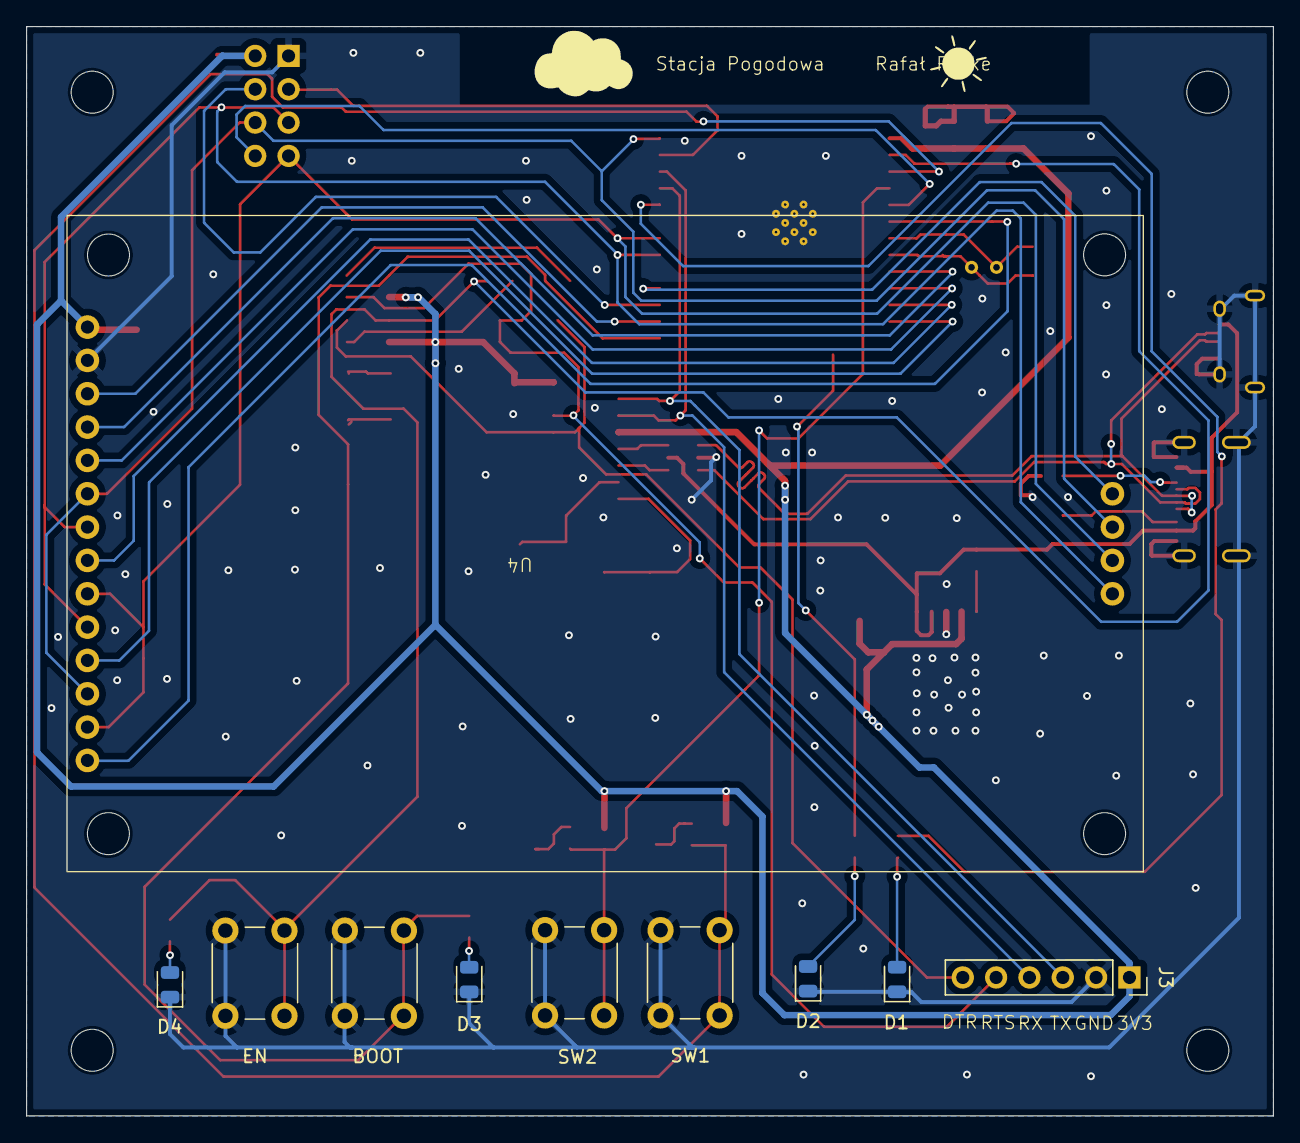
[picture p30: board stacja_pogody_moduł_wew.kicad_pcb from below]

Board: 2 copper layers, 95.0 x 83.0 mm, 60 parts (10 on the bottom side), 47 nets.

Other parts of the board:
BOOT: SW_MEC_5G; SW_PUSH_6mm_H4.3mm
EN: SW_MEC_5G; SW_PUSH_6mm_H4.3mm

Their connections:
/ESP_BOOT: BOOT.1 (A); also elsewhere on the board
/ESP_ENABLE: EN.1 (A); also elsewhere on the board
GND: BOOT.2 (A), EN.2 (A); also elsewhere on the board

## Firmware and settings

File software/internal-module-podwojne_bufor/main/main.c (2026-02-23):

#include <stdio.h>
#include <time.h>
#include <math.h>
#include "freertos/FreeRTOS.h"
#include "freertos/task.h"
#include "freertos/semphr.h"
#include "freertos/queue.h"
#include "esp_system.h"
#include "esp_log.h"
#include "esp_spiffs.h"
#include "nvs_flash.h"

// Sterowniki sprzętowe
#include "gpio_init.h"
#include "spi_init.h"
#include "uart_init.h"
#include "nrf.h"
#include "lcd.h"
#include "ili9340.h"
#include "fontx.h"

// Twoje moduły
#include "wifi_project.h"
#include "sntp.h"
#include "Config.h" // Upewnij się, że BUTTON_1 jest tu zdefiniowany

// --- KONFIGURACJA WYKRESÓW ---
#define GRAPH_X_START 40
#define GRAPH_Y_START 130
#define GRAPH_WIDTH   240
#define GRAPH_HEIGHT  70  
#define GRAPH_POINTS  100

// --- KONFIGURACJA PEŁNEGO EKRANU ---
#define FS_CHUNK_HEIGHT  60

// Marginesy (Tu robimy miejsce na napisy!)
#define FS_MARGIN_TOP    40
#define FS_MARGIN_BOTTOM 25
#define FS_MARGIN_LEFT   35   // 35px wolnego miejsca z lewej na "35", "15"
#define FS_MARGIN_RIGHT  35   // 35px wolnego miejsca z prawej na "80", "20"

// Obliczamy szerokość SAMEGO OBSZARU RYSOWANIA (Wykresu)
// 320 - 35 - 35 = 250 pikseli szerokości na wykres
#define FS_GRAPH_WIDTH   (LCD_WIDTH - FS_MARGIN_LEFT - FS_MARGIN_RIGHT)
#define FS_GRAPH_HEIGHT  (LCD_HEIGHT - FS_MARGIN_TOP - FS_MARGIN_BOTTOM)

// Start Y bez zmian
#define FS_GRAPH_Y_START FS_MARGIN_TOP

// Rozmiar bufora pozostaje bez zmian (38.4 KB) - buforujemy całą szerokość ekranu
#define MAX_CHART_BUF_SIZE (LCD_WIDTH * FS_CHUNK_HEIGHT * 2)

// ZAKRESY POMIAROWE
#define MIN_TEMP 15.0f
#define MAX_TEMP 35.0f
#define MIN_HUM  15.0f
#define MAX_HUM  80.0f
#define MIN_PRESS 980.0f
#define MAX_PRESS 1040.0f

// --- ZMIENNE GLOBALNE ---
uint16_t *chart_buffer = NULL; // Główny bufor graficzny
uint16_t *text_buffer = NULL;  // Mały bufor na teksty

// Dane historyczne
float hist_temp[GRAPH_POINTS] = {0};
float hist_hum[GRAPH_POINTS]  = {0};
float hist_press[GRAPH_POINTS]= {0};
int   hist_idx = 0;           
bool  hist_full = false;   

// Obiekty systemowe
TFT_t lcd;
spi_device_handle_t nrf_handle = NULL;
FontxFile fx[2];
SemaphoreHandle_t xSpiMutex = NULL;
QueueHandle_t xSensorQueue = NULL;

// --- INICJALIZACJE ---
void init_spiffs() {
    esp_vfs_spiffs_conf_t conf = { .base_path = "/spiflash", .partition_label = NULL, .max_files = 5, .format_if_mount_failed = true };
    esp_vfs_spiffs_register(&conf);
}

void init_nvs() {
    esp_err_t ret = nvs_flash_init();
    if (ret == ESP_ERR_NVS_NO_FREE_PAGES) { nvs_flash_erase(); nvs_flash_init(); }
}

// --- TASKS ---
void nrf_receiver_task(void *pvParameters) {
    SensorData localData = {0};
    while(1) {
        if (xSpiMutex && xSemaphoreTake(xSpiMutex, pdMS_TO_TICKS(100))) {
            nrf_receive_data(nrf_handle, &localData);
            xSemaphoreGive(xSpiMutex);
            xQueueOverwrite(xSensorQueue, &localData);
        }
        vTaskDelay(pdMS_TO_TICKS(100));
    }
}

void collect_time_task(void *pvParameters) {
    // Pamiętaj o ustawieniu poprawnego SSID i Hasła!
    if (wifi_connect_station(SSID, PASSWORD)) { 
        sntp_init_module(); 
        setenv("TZ", "CET-1CEST,M3.5.0,M10.5.0/3", 1); 
        tzset();
        while(1) { wait_for_time_sync(); vTaskDelay(pdMS_TO_TICKS(3600 * 1000)); }
    } else { 
        vTaskDelete(NULL); 
    }
}

/*uint8_t calc_battery_percent(uint16_t mv) { //liniowe przeliczanie
    if (mv >= 3000) return 100;
    if (mv <= 2000) return 0;
    return (mv-2000) / 10;
}*/

uint8_t calc_battery_percent(uint16_t mv) { //nieliniowe - proba nasladowania cha-ki dla baterii alkaicznych
    // 1. Zabezpieczenie górne (świeże baterie często mają nieco ponad 3.0V)
    if (mv >= 2800) return 100;
    
    // 2. Górny przedział: 2600mV - 2800mV (spadek z 100% do 80%)
    if (mv > 2600) return 80 + ((mv - 2600) / 10);
    
    // 3. Środkowy, "płaski" przedział: 2400mV - 2600mV (spadek z 80% do 50%)
    // Bateria spędza tu najwięcej czasu swojego życia.
    if (mv > 2400) return 50 + (((mv - 2400) * 30) / 200);
    
    // 4. Dolny przedział: 2200mV - 2400mV (spadek z 50% do 20%)
    if (mv > 2200) return 20 + (((mv - 2200) * 30) / 200);
    
    // 5. Krytyczny spadek: 2000mV - 2200mV (spadek z 20% do 0%)
    if (mv > 2000) return (mv - 2000) / 10;
    
    // 6. Zabezpieczenie dolne (poniżej 2.0V)
    return 0;
}

// ==========================================
// FUNKCJE GRAFICZNE
// ==========================================

// Rysowanie tekstu bez migotania
void draw_text_buffered(int x, int y, char *str, uint16_t text_color) {
    if (!text_buffer) return; 

    int max_w = 180; 
    int h = 20;  
    int w = max_w;
    if (x + w > LCD_WIDTH) w = LCD_WIDTH - x;

    // Czyścimy bufor (białe tło)
    for (int i = 0; i < w * h; i++) text_buffer[i] = 0xFFFF;

    uint8_t fonts[256];
    uint8_t font_w, font_h;
    int cur_x = 0;
    char *p = str;

    while (*p) {
        if (GetFontx(fx, (uint8_t)*p, fonts, &font_w, &font_h)) {
            for (int cy = 0; cy < font_h; cy++) {
                for (int cx = 0; cx < font_w; cx++) {
                    if (fonts[(cy * ((font_w + 7) / 8)) + (cx / 8)] & (0x80 >> (cx % 8))) {
                        int bx = cur_x + cx;
                        int by = cy + (h - font_h);
                        if (bx < w && by < h && by >= 0) {
                            text_buffer[by * w + bx] = (text_color >> 8) | (text_color << 8);
                        }
                    }
                }
            }
            cur_x += font_w;
        }
        p++;
    }
    ili9341_draw_image(&lcd, x, y - h, w, h, text_buffer);
}

// Funkcje pomocnicze do rysowania w buforze
void drawPixelChart(int x, int y, uint16_t color) {
    chart_buffer[y * GRAPH_WIDTH + x] = (color >> 8) | (color << 8);
}

void drawLineChart(int x0, int y0, int x1, int y1, uint16_t color) {
    int dx = abs(x1 - x0), sx = x0 < x1 ? 1 : -1;
    int dy = -abs(y1 - y0), sy = y0 < y1 ? 1 : -1;
    int err = dx + dy, e2;
    while (1) {
        if (x0 >= 0 && x0 < GRAPH_WIDTH && y0 >= 0 && y0 < GRAPH_HEIGHT)
            drawPixelChart(x0, y0, color);
        if (x0 == x1 && y0 == y1) break;
        e2 = 2 * err;
        if (e2 >= dy) { err += dy; x0 += sx; }
        if (e2 <= dx) { err += dx; y0 += sy; }
    }
}

void drawRectChart(int x, int y, int w, int h, uint16_t color) {
    drawLineChart(x, y, x + w - 1, y, color);
    drawLineChart(x, y + h - 1, x + w - 1, y + h - 1, color);
    drawLineChart(x, y, x, y + h - 1, color);
    drawLineChart(x + w - 1, y, x + w - 1, y + h - 1, color);
}

uint16_t map_val(float value, float min_v, float max_v) {
    if (value < min_v) value = min_v;
    if (value > max_v) value = max_v;
    float ratio = (value - min_v) / (max_v - min_v);
    return GRAPH_HEIGHT - 2 - (uint16_t)(ratio * (GRAPH_HEIGHT - 4));
}

void add_to_history(SensorData *d) {
    hist_temp[hist_idx] = d->temp_hundredths / 100.0f;
    hist_hum[hist_idx]  = d->hum_x1024 / 1024.0f;
    hist_press[hist_idx]= d->pressure_pa / 100.0f;
    hist_idx++;
    if (hist_idx >= GRAPH_POINTS) { hist_idx = 0; hist_full = true; }
}

// RENDEROWANIE MAŁEGO WYKRESU
void render_chart() {
    if (!chart_buffer) return;
    
    // Tło
    for (int i = 0; i < GRAPH_WIDTH * GRAPH_HEIGHT; i++) chart_buffer[i] = 0xFFFF;
    
    // Siatka
    int mid_y = GRAPH_HEIGHT / 2;
    for(int x=1; x<GRAPH_WIDTH-1; x+=4) drawPixelChart(x, mid_y, GRAY);

    // Wykresy
    int count = hist_full ? GRAPH_POINTS : hist_idx;
    int start_i = hist_full ? hist_idx : 0;
    float step_x = (float)(GRAPH_WIDTH - 2) / (float)(GRAPH_POINTS - 1);

    for (int i = 0; i < count - 1; i++) {
        int idx_now = (start_i + i) % GRAPH_POINTS;
        int idx_next = (start_i + i + 1) % GRAPH_POINTS;
        int x1 = 1 + (int)(i * step_x);
        int x2 = 1 + (int)((i + 1) * step_x);
        
        drawLineChart(x1, map_val(hist_temp[idx_now], MIN_TEMP, MAX_TEMP), x2, map_val(hist_temp[idx_next], MIN_TEMP, MAX_TEMP), RED);
        drawLineChart(x1, map_val(hist_hum[idx_now], MIN_HUM, MAX_HUM), x2, map_val(hist_hum[idx_next], MIN_HUM, MAX_HUM), BLUE);
        drawLineChart(x1, map_val(hist_press[idx_now], MIN_PRESS, MAX_PRESS), x2, map_val(hist_press[idx_next], MIN_PRESS, MAX_PRESS), GREEN);
    }
    
    // Ramka
    drawRectChart(0, 0, GRAPH_WIDTH, GRAPH_HEIGHT, BLACK);

    // Wysyłanie
    int chunk = 10; 
    for (int y = 0; y < GRAPH_HEIGHT; y += chunk) {
        int h = (y + chunk > GRAPH_HEIGHT) ? (GRAPH_HEIGHT - y) : chunk;
        ili9341_draw_image(&lcd, GRAPH_X_START, GRAPH_Y_START + y, GRAPH_WIDTH, h, &chart_buffer[y * GRAPH_WIDTH]);
    }
}

// x i y są RELATYWNE względem ramki wykresu (0,0 to lewy górny róg wykresu,
void draw_relative_line(uint16_t *buff, int chunk_start_y, int x0, int y0, int x1, int y1, uint16_t color) {
    int dx = abs(x1 - x0), sx = x0 < x1 ? 1 : -1;
    int dy = -abs(y1 - y0), sy = y0 < y1 ? 1 : -1;
    int err = dx + dy, e2;

    while (1) {
        // Przeliczamy Y absolutny na lokalny w pasku (chunck)
        int local_y = y0 - chunk_start_y;

        // Sprawdzamy czy punkt jest w buforze
        // UWAGA: Używamy FS_GRAPH_WIDTH zamiast LCD_WIDTH, bo bufor jest teraz węższy!
        if (local_y >= 0 && local_y < FS_CHUNK_HEIGHT && x0 >= 0 && x0 < FS_GRAPH_WIDTH) {
            buff[local_y * FS_GRAPH_WIDTH + x0] = (color >> 8) | (color << 8);
        }

        if (x0 == x1 && y0 == y1) break;
        e2 = 2 * err;
        if (e2 >= dy) { err += dy; x0 += sx; }
        if (e2 <= dx) { err += dx; y0 += sy; }
    }
}

// Wersja POGRUBIONA (tylko do linii danych na dużym wykresie)
void draw_relative_line_Thick(uint16_t *buff, int chunk_start_y, int x0, int y0, int x1, int y1, uint16_t color) {
    // 1. Linia główna
    draw_relative_line(buff, chunk_start_y, x0, y0, x1, y1, color);
    // 2. Linia pogrubiająca (1px niżej)
    draw_relative_line(buff, chunk_start_y, x0, y0 + 1, x1, y1 + 1, color);
    // 3. Linia pogrubiająca (1px niżej)
    draw_relative_line(buff, chunk_start_y, x0, y0 + 2, x1, y1 + 2, color);
    // 4. Linia pogrubiająca (1px niżej)
    draw_relative_line(buff, chunk_start_y, x0, y0 + 3, x1, y1 + 3, color);
}

// Funkcja pomocnicza dla Full Screen (z obsługą marginesów bufora)
void draw_fs_line(uint16_t *buff, int chunk_start_y, int x0, int y0, int x1, int y1, uint16_t color) {
    int dx = abs(x1 - x0), sx = x0 < x1 ? 1 : -1;
    int dy = -abs(y1 - y0), sy = y0 < y1 ? 1 : -1;
    int err = dx + dy, e2;
    while (1) {
        int local_y = y0 - chunk_start_y;
        // Sprawdzamy, czy punkt mieści się w AKTUALNYM pasku bufora oraz w szerokości ekranu
        if (local_y >= 0 && local_y < FS_CHUNK_HEIGHT && x0 >= 0 && x0 < LCD_WIDTH) {
            buff[local_y * LCD_WIDTH + x0] = (color >> 8) | (color << 8);
        }
        if (x0 == x1 && y0 == y1) break;
        e2 = 2 * err;
        if (e2 >= dy) { err += dy; x0 += sx; }
        if (e2 <= dx) { err += dx; y0 += sy; }
    }
}

// RENDEROWANIE PEŁNOEKRANOWE (GRUBSZE LINIE DANYCH, CIENKA RESZTA)
void render_fullscreen_chart() {
    if (!chart_buffer) return;

    #define MAP_FS(val, min, max) ((FS_GRAPH_Y_START + FS_GRAPH_HEIGHT - 1) - (int)(((val - min) / (max - min)) * (FS_GRAPH_HEIGHT - 1)))

    for (int chunk_start_y = FS_GRAPH_Y_START; chunk_start_y < (FS_GRAPH_Y_START + FS_GRAPH_HEIGHT); chunk_start_y += FS_CHUNK_HEIGHT) {
        
        // 1. Czyścimy
        int buf_size = FS_GRAPH_WIDTH * FS_CHUNK_HEIGHT;
        for (int i = 0; i < buf_size; i++) chart_buffer[i] = 0xFFFF;

        // 2. Siatka (CIENKA)
        for (int gy = FS_GRAPH_Y_START; gy < (FS_GRAPH_Y_START + FS_GRAPH_HEIGHT); gy += 40) { 
            int local_y = gy - chunk_start_y;
            if (local_y >= 0 && local_y < FS_CHUNK_HEIGHT) {
                for(int x = 0; x < FS_GRAPH_WIDTH; x+=4) {
                    chart_buffer[local_y * FS_GRAPH_WIDTH + x] = (0xCE79 >> 8) | (0xCE79 << 8);
                }
            }
        }

        // 3. Dane (GRUBSZE)
        float step_x = (float)FS_GRAPH_WIDTH / (float)(GRAPH_POINTS - 1);
        int count = hist_full ? GRAPH_POINTS : hist_idx;
        int start_i = hist_full ? hist_idx : 0;

        for (int i = 0; i < count - 1; i++) {
            int idx_now = (start_i + i) % GRAPH_POINTS;
            int idx_next = (start_i + i + 1) % GRAPH_POINTS;
            
            int x1 = (int)(i * step_x);
            int x2 = (int)((i + 1) * step_x);

            // TU ZOSTAWIONE: draw_relative_line_Thick
            draw_relative_line_Thick(chart_buffer, chunk_start_y, x1, MAP_FS(hist_temp[idx_now], MIN_TEMP, MAX_TEMP), x2, MAP_FS(hist_temp[idx_next], MIN_TEMP, MAX_TEMP), RED);
            draw_relative_line_Thick(chart_buffer, chunk_start_y, x1, MAP_FS(hist_hum[idx_now], MIN_HUM, MAX_HUM), x2, MAP_FS(hist_hum[idx_next], MIN_HUM, MAX_HUM), BLUE);
            draw_relative_line_Thick(chart_buffer, chunk_start_y, x1, MAP_FS(hist_press[idx_now], MIN_PRESS, MAX_PRESS), x2, MAP_FS(hist_press[idx_next], MIN_PRESS, MAX_PRESS), GREEN);
        }

        // 4. Ramka (CIENKA)
        int h_max = FS_GRAPH_HEIGHT - 1; 
        int w_max = FS_GRAPH_WIDTH - 1;  
        
        draw_relative_line(chart_buffer, chunk_start_y, 0, FS_GRAPH_Y_START, 0, FS_GRAPH_Y_START + h_max, BLACK);       
        draw_relative_line(chart_buffer, chunk_start_y, w_max, FS_GRAPH_Y_START, w_max, FS_GRAPH_Y_START + h_max, BLACK); 
        draw_relative_line(chart_buffer, chunk_start_y, 0, FS_GRAPH_Y_START, w_max, FS_GRAPH_Y_START, BLACK);             
        draw_relative_line(chart_buffer, chunk_start_y, 0, FS_GRAPH_Y_START + h_max, w_max, FS_GRAPH_Y_START + h_max, BLACK); 

        // 5. Wyślij
        int h = FS_CHUNK_HEIGHT;
        if (chunk_start_y + h > (FS_GRAPH_Y_START + FS_GRAPH_HEIGHT)) 
            h = (FS_GRAPH_Y_START + FS_GRAPH_HEIGHT) - chunk_start_y;

        if (h > 0) {
            ili9341_draw_image(&lcd, FS_MARGIN_LEFT, chunk_start_y, FS_GRAPH_WIDTH, h, chart_buffer);
        }
        
        vTaskDelay(1); 
    }
}
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
void app_main(void) {
    init_nvs();
    
    // 1. REZERWACJA PAMIĘCI GRAFICZNEJ (BARDZO WAŻNE!)
    // Alokujemy pamięć raz na starcie. Zapobiega to fragmentacji i błędom.
    ESP_LOGI("MEM", "Rezerwacja RAM dla grafiki...");
    chart_buffer = heap_caps_malloc(MAX_CHART_BUF_SIZE, MALLOC_CAP_DMA);
    text_buffer  = heap_caps_malloc(180 * 20 * 2, MALLOC_CAP_DMA);

    if (!chart_buffer || !text_buffer) {
        ESP_LOGE("MEM", "Brak pamieci RAM na starcie! Restart...");
        esp_restart();
    }
    
    // Wstępne czyszczenie
    for(int i=0; i<MAX_CHART_BUF_SIZE/2; i++) chart_buffer[i] = 0xFFFF;

    // 2. Inicjalizacja RTOS
    xSpiMutex = xSemaphoreCreateMutex();
    xSensorQueue = xQueueCreate(1, sizeof(SensorData));
    
    // 3. Inicjalizacja Sprzętu
    gpio_init();
    spi_init();
    uart_init();
    nrf_init(&nrf_handle);
    init_spiffs();
    lcd_init();
    
    // Fonty
    InitFontx(fx, "/spiflash/ILMH16XB.FNT", ""); 
    OpenFontx(fx);

    // 4. Start Tasków
    // GUI dostaje więcej pamięci stosu (16KB) dla bezpieczeństwa przy dużych operacjach
    xTaskCreate(nrf_receiver_task, "NRF", 4096, NULL, 5, NULL);
    xTaskCreate(collect_time_task, "TIME", 8192, NULL, 5, NULL); 
    xTaskCreate(lcd_gui_task, "GUI", 16384, NULL, 5, NULL); 
}

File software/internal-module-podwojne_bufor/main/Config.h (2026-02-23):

#pragma once
#define BUTTON_1 GPIO_NUM_36
#define BUTTON_2 GPIO_NUM_39

#define LED1 GPIO_NUM_13
#define LED2 GPIO_NUM_21

// SPI Pins
#define SPI_MISO GPIO_NUM_19
#define SPI_MOSI GPIO_NUM_23
#define SPI_SCLK GPIO_NUM_18

// NRF Pins
#define NRF_CE_PIN GPIO_NUM_22
#define NRF_CSN_PIN GPIO_NUM_16
//NRF Settings
#define RX_ADDRESS_VAL {'A', 'T', '4', '1', '4'}
#define Channel 76
#define NRF_SPEED 0x07 //2Mbps, 0dBm

// --- STRUKTURA DANYCH (14 bajtów) ---
typedef struct __attribute__((packed)) {
    int32_t temp_hundredths;
    uint32_t pressure_pa;
    uint32_t hum_x1024;
    uint16_t battery_mv;
} SensorData;

// LCD Pins
#define CS_PIN GPIO_NUM_4
#define DC_PIN GPIO_NUM_26
#define RESET_PIN GPIO_NUM_25
#define BL_PIN GPIO_NUM_27
//LCD Settings
#define LCD_TYPE 0x7789 //lub 0x9341
#define LCD_WIDTH  320
#define LCD_HEIGHT 240
#define LCD_ORIENTATION_1 0x36 // Portrait  //dla ili9341 0x36
#define LCD_ORIENTATION_2 0xE8 // Landscape //dla ili9341 0xA8
//Optional LCD
#define T_CS GPIO_NUM_14
#define SD_CS GPIO_NUM_17

#define NRF_IRQ GPIO_NUM_34
#define T_IRQ GPIO_NUM_35

// NTC
#define SSID "POCO X3 NFC"
#define PASSWORD "Rafik123"
#define SNTP_SERVER "pool.ntp.org"

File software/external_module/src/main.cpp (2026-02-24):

/*
 * KOMPLETNY PLIK DIAGNOSTYCZNY DLA ATTINY414 + NRF24L01
 * Funkcje: Nadawanie + Wykrywanie Resetu Radia (Brown-out detection)
 */

#include <avr/io.h>
#include <util/delay.h>
#include <avr/interrupt.h>
#include <stdio.h>
#include <string.h>

#include "Config.h"
#include "SPI.h"
#include "NRF24L01.h"
#include "SoftwareI2C.h"
#include "BME280.h"
#include "RTC_sleep.h"

// Makra LED
#define LED_ON()   (LED_PORT.OUTSET = LED_PIN)
#define LED_OFF()  (LED_PORT.OUTCLR = LED_PIN)

// Funkcja pomocnicza do mrugania (ilość razy, czas ms)
void blink_led(uint8_t count, uint16_t ms) {
    for (uint8_t i = 0; i < count; i++) {
        LED_ON();
        for(uint16_t d=0; d<ms; d++) _delay_ms(1);
        LED_OFF();
        for(uint16_t d=0; d<ms; d++) _delay_ms(1);
    }
}

uint16_t get_battery_mv(void) {
    // 1. Ustaw wewnętrzne napięcie odniesienia (VREF) dla ADC na 1.5V
    VREF.CTRLA = VREF_ADC0REFSEL_1V5_gc;
    
    // 2. Skonfiguruj ADC: 
    // - Napięciem referencyjnym (maksymalnym) dla ADC staje się VDD (bateria)
    // - Ustawiamy preskaler na DIV16 (bezpieczna wartość dla standardowego zegara)
    ADC0.CTRLC = ADC_PRESC_DIV16_gc | ADC_REFSEL_VDDREF_gc; 
    
    // 3. Jako kanał wejściowy ADC wybieramy nasze stabilne 1.5V (INTREF)
    ADC0.MUXPOS = ADC_MUXPOS_INTREF_gc;
    
    // 4. Włącz przetwornik ADC
    ADC0.CTRLA = ADC_ENABLE_bm;

    _delay_us(100);
    
    // 5. Ślepy pomiar (Dummy read) - nota Microchip zaleca odrzucenie pierwszego 
    // wyniku po uruchomieniu ADC lub zmianie napięcia odniesienia, aby ustabilizować układ
    ADC0.COMMAND = ADC_STCONV_bm; // Start konwersji
    while (!(ADC0.INTFLAGS & ADC_RESRDY_bm)); // Czekaj na koniec
    ADC0.INTFLAGS = ADC_RESRDY_bm; // Wyczyść flagę
    
    // 6. Właściwy pomiar
    ADC0.COMMAND = ADC_STCONV_bm;
    while (!(ADC0.INTFLAGS & ADC_RESRDY_bm));
    ADC0.INTFLAGS = ADC_RESRDY_bm;
    
    // Zapisz wynik (10-bitowy)
    uint16_t adc_result = ADC0.RES;
    
    // 7. Natychmiast wyłącz ADC, żeby nie marnował energii podczas snu układu!
    ADC0.CTRLA &= ~ADC_ENABLE_bm;
    
    // 8. Obliczenia
    // Przekształcony wzór dający wynik od razu w miliwoltach:
    // 1500 (bo 1.5V = 1500mV) * 1024 (rozdzielczość przetwornika) / wynik ADC
    uint32_t vdd_mv = (1500UL * 1024UL) / adc_result;

    return (uint16_t) vdd_mv;
}

int main(void) {
    _PROTECTED_WRITE(CLKCTRL.MCLKCTRLB, 0); 

    LED_PORT.DIRSET = LED_PIN; // LED jako wyjście
    LED_OFF();

    SPI_init();
    TWI_Init();
    NRF_init();
    RTC_Init();

    sei();//włączamy globalne przerwania
    
    NRF_set_tx_mode(); //ustawienie nrf jako nadajnik
    
    BME280_Init();
    BME280_ReadCalibration();
    sensor_packet_t pkt;

    while (1) {
        uint8_t data[8];
        BME280_ReadBytes(0xF7, data, 8);

        // ciśnienie (20 bit)
        uint32_t raw_press = ((uint32_t)data[0] << 12) | ((uint32_t)data[1] << 4) | ((uint32_t)data[2] >> 4);

        // temperatura (20 bit)
        uint32_t raw_temp  = ((uint32_t)data[3] << 12) | ((uint32_t)data[4] << 4) | ((uint32_t)data[5] >> 4);

        // wilgotność (16 bit)
        uint32_t raw_hum   = ((uint32_t)data[6] << 8)  | ((uint32_t)data[7]);
        
        NRF_write_reg(0x00, 0x0A); //na nowo włączamy zasilanie radia na czas transmisji
        _delay_ms(10); //uśpienie potrzebne na uruchomienie się oscylatora układu

        //Tutaj jest kompensacja
        
        pkt.temp_hundredths = BME280_Compensate_T(raw_temp); //0.01°C
        pkt.pressure_pa    = BME280_Compensate_P(raw_press); //Pa
        pkt.hum_x1024      = BME280_Compensate_H(raw_hum);
        pkt.battery_mv         = get_battery_mv();
        
        NRF_write_reg(0x07, 0x70); //wyczyszczenie flag statusu

        NRF_send_packet(&pkt); //wyślij dane
        //blink_led(3, 100); //sygnalizacja wysłania danych
        _delay_ms(10); //odkomentowac w przypaku zakomentowania blink_led();
        NRF_write_reg(0x00,0x00); //całkowite uśpienie radia nrf na czas braku transmisji

        //_delay_ms(5000); //uśpienie tylko w trakcie testu komunikacji
        //zamiast delay go to sleep
        GoToSleep(); 

    }
}

// Obsługa przerwania - budzik zadzwonił
ISR(RTC_PIT_vect) {
    // Wyczyść flagę przerwania, żeby nie wpaść w pętlę
    RTC.PITINTFLAGS = RTC_PI_bm;
}

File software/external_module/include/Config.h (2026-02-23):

#include <avr/io.h>
#define F_CPU 20000000UL // 20 MHz

#define SLEEP_SCALER RTC_PERIOD_CYC8192_gc
/* inne dzielniki czasu uspania:
    RTC_PERIOD_CYC1024_gc  = 1 sekunda
    RTC_PERIOD_CYC4096_gc  = 4 sekundy
    RTC_PERIOD_CYC8192_gc  = 8 sekund
    RTC_PERIOD_CYC16384_gc = 16 sekund
    RTC_PERIOD_CYC32768_gc = 32 sekundy

*/

/*w celu optymalizacji zużycia enrgii zalecamy zakomentować 
blink_led(3, 100); //sygnalizacja wysłania danych w pliku main.cpp
*/

#define LED_PORT  PORTA
#define LED_PIN   PIN6_bm //lub PIN6_bm w zależności od płytki

#define NRF_CE_PIN PIN5_bm
#define NRF_CSN_PIN PIN4_bm

#define I2C_PORT    PORTB
#define SCL_PIN     PIN0_bm  // Jeśli w teście działało odwrotnie, zamień na PIN1_bm
#define SDA_PIN     PIN1_bm  // Jeśli w teście działało odwrotnie, zamień na PIN0_bm

#define SPI_PORT PORTA
#define MOSI_PIN PIN1_bm
#define MISO_PIN PIN2_bm
#define SCK_PIN PIN3_bm

#define Channel 76
#define NRF_SPEED 0x07 //2Mbps, 0dBm
#define SPI_SEND_ADDRESS() do { \
    SPI_transfer('A'); \
    SPI_transfer('T'); \
    SPI_transfer('4'); \
    SPI_transfer('1'); \
    SPI_transfer('4'); \
} while(0) //wysyła 5 bajtów adresu

#define BME280_ADDR 0x76 //lub 0x77 zaleznie od plytki

typedef struct __attribute__((packed)) {//to jest struktura 14 bajtowa, nrf może przyjąc 32, dzieki struktorze packet wyslemy cale 14 bajtow za jednym zamachem
    int32_t temp_hundredths;
    uint32_t pressure_pa;
    uint32_t hum_x1024;
    uint16_t battery_mv;
} sensor_packet_t; //musi być taka sama na odbiorniku (ESP32)

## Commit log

2026-02-13 Pierwsza wersja publiczna
    [Wireless Radio Transmitter and Receiver nRF24L01.STEP, lcd_019.step, lcd_fusion.FCStd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]
2026-02-22 Dodano wskaznik baterii, wlaczono BOD, wysylanie co 8s, wstepny zarys obudowy
    [2AA.stl, 2AA_CAD-Body.step, 2AA_CAD.fcstd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]
2026-02-23 Poprawiono dokladnosc odczytu baterii, teraz wysylane do mV do stacji
    [obudowa_zewn-Zawartość.step, obudowa_zewn-wieczko.step, obudowa_zewn.FCStd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]
